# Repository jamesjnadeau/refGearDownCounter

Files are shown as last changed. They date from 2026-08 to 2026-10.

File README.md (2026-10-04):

# Ref Gear — Down Counter

Football down counters — the wrist-worn devices a referee uses to track which
down it is. This repository covers the **mechanical** ones. Both models are
here as OpenSCAD source, each with a test suite, and can be built from this
repository alone:

- [down-indicator-selector/](down-indicator-selector/) — the slider down
  counter, three printed parts.
- [down-indicator-string/](down-indicator-string/) — the finger-loop down
  indicator, one printed part.

The slider began in Onshape and was converted on 2026-08-25. The Onshape
documents are still recorded below, because the band lugs exist only there
and are not yet in the OpenSCAD model.

## These are not the Watchy ref counter

The **electronic** ref counter — an ESP32-C6 board running countdown timers on
a Watchy e-paper panel — is a separate project in its own repository,
[watchy-ref-counter](https://github.com/jamesjnadeau/watchy-ref-counter). That
is a different product with different hardware and different geometry.

The two are related only in purpose — both are officiating aids for football.
**Do not carry dimensions between them.** An earlier revision of the lugs spec
did exactly that, projecting a ~43 x 53mm case from the Watchy waterproof case
spec onto a part that actually measures 34 x 79mm, and every figure derived
from it was wrong. This repository was split out of that one on 2026-08-23 so
the two cannot be confused again.

## What you need to build

Both models build with the same tools. Nothing else is needed, and no file in
the repository has to be changed first.

| Tool | Version | Needed for |
| --- | --- | --- |
| [OpenSCAD](https://openscad.org/) | 2021.01 | `make stl` and `make test`. The tests' exact-volume figures were verified against this release; another release may shift them. |
| GNU Make | 4.4.1 used; any recent release should do | `make stl` and `make test` |
| Python | **3.12 or newer**, with the `venv` module | `make test` only. The pinned `numpy` and `scipy` do not install on anything older. |
| DejaVu Sans (font) | any | The slider's numerals. It is not vendored. See the warning below. |

The finger-loop model's fonts (Archivo) are vendored in
`down-indicator-string/fonts/` and need no installation.

`make test` creates a `.venv` in the model's directory and installs the pinned
packages from `requirements.txt` (`trimesh`, `numpy`, `scipy`, `rtree`,
`pytest`), so the first run needs network access to PyPI. `make stl` needs
neither Python nor the network.

On Debian 13 this is everything:

    apt-get install openscad make python3 python3-venv fonts-dejavu-core

Then, in either model's directory:

    make stl      # the printable STL files, in build/
    make test     # render the model and check it against the tests

**If DejaVu Sans is missing, `make stl` does not fail and prints no warning.**
OpenSCAD 2021.01 substitutes another face without a word, and the slider's
numerals come out in the wrong shape. The tie bar that holds the middle of the
"4" in place is positioned for DejaVu Sans. So run `make test` once on a new
machine before printing the top shell. Tried on 2026-10-03 with DejaVu Sans
hidden and Archivo substituted: `make stl` exited normally, and `make test`
failed two of its 64 tests. A different substitute face has not been tried and
may not be caught.

Checked on 2026-10-03 on Debian 13 with the versions above and Python 3.13.5.
Other operating systems have not been tried.

## Contents

| File | What it is |
| --- | --- |
| [2026-08-22-band-lugs-design.md](2026-08-22-band-lugs-design.md) | Design and as-built record for the spring-bar band lugs, the squared end corners, and the removal of the unprintable "4" counter. Built 2026-08-22, not yet printed. |
| [2026-08-24-finger-loop-indicator-design.md](2026-08-24-finger-loop-indicator-design.md) | Design for the finger-loop down indicator: a wrist body anchoring a bungee cord that loops over a finger. Modelled in OpenSCAD under `down-indicator-string/`, not in Onshape. |
| [down-indicator-string/](down-indicator-string/) | The OpenSCAD model for the above, with a `pytest` suite that renders it and asserts against the mesh. |
| [down-indicator-selector/](down-indicator-selector/) | All three parts of the slider down counter, converted out of Onshape into OpenSCAD on 2026-08-25, with the same kind of test suite and Onshape's own exports kept alongside as reference meshes. |
| Parts lists | Draft, with unknowns marked. [Slider](down-indicator-selector/PARTS.md), [finger loop](down-indicator-string/PARTS.md). |
| Assembly steps | Draft, with unknowns marked. [Slider](down-indicator-selector/ASSEMBLY.md), [finger loop](down-indicator-string/ASSEMBLY.md). |
| [AGENTS.md](AGENTS.md) | Working notes for agents. Chiefly: if you cannot delete something you created in Onshape, hand back an explicit cleanup list rather than leaving orphans unmentioned. |
| [LICENSE](LICENSE) | Open Community License v1.1, verbatim. See [Licence](#licence). |

## The mechanical slider down counter

A three-part printed slider. A knob rides in a slot in the top plate and
indexes between four stations; the numbers 1–4 engraved alongside the slot
read off the current down.

### The move to OpenSCAD

All three parts have been converted to OpenSCAD and live in
[down-indicator-selector/](down-indicator-selector/), so the counter can be
built without opening Onshape. They are conversions of the **original**, so
they carry no lugs. That README records what the conversion does and does not
carry over — chiefly the typeface, the two non-tangent corner arcs, and the
floating counter of the 4, which is the one thing deliberately fixed rather
than reproduced.

Two things it turned up that were not recorded anywhere before:

- **How the three parts stack.** The assembly in Onshape is empty, so this was
  read off the geometry: the bottom shell seats against the cavity ceiling and
  stands 1.1mm proud of the skirt, the button's flange lifts 0.4mm in its
  pocket, and its boss stands 1.9mm clear of the top face. Case thickness
  8.2mm.
- **The bottom shell does not fit the cavity.** The cavity's 3° draft makes it
  widest at the ceiling and narrowest at the mouth the bottom shell enters
  through, leaving about 0.18mm of interference per side. The owner confirmed
  on 2026-10-03 that the two shells are meant to press together.

### Onshape models

| | |
| --- | --- |
| Original (do not modify) | `3db840dfeff4095d8508aa97`, workspace `468073bad9de0e9ca2287d8a` |
| Working copy (edit this) | `00b1e7c9d07aec2789568fab`, workspace `f48449999f7a6cf5db9ca973` |

Both documents are the work of James Nadeau, who authored the original model
and holds the rights licensed under [OCL v1.1](#licence). Nothing here is
derived from a third party's design.

The copy was made by hand — the API cannot clone a document. Working in the
copy keeps the original intact and preserves the parametric feature tree.

Elements in the working copy:

| Element | ID |
| --- | --- |
| `top` | `c8988bf041b2bcfcdef1a5a4` |
| `Bottom` | `683c1e415929ccc1972183f3` |
| `button` | `549b45f983101a2bbf977db6` |
| `Assembly 1` | `1e37806a3e2b45bacbff18d4` — **empty**, no instances or mates |
| `BOM : Assembly 1` | `e0e801cd186e08b5a415de05` |

Because the assembly carries nothing, there is no mate data describing how the
parts stack. The two shells are nonetheless modelled in a shared coordinate
space: the top's inner end face and the bottom's outer end face both sit at
y = −15, so the shells nest directly.

### Parts, as measured 2026-08-22

| Part | Size | Notes |
| --- | --- | --- |
| `top` | 79.00 x 34.00 x 7.10mm | Solid plate z = 0 to +3.10; 2.0mm skirt wall z = −4.00 to 0 around the cavity the bottom nests in. Carries the slot, the numbers, and now the lugs. |
| `Bottom` | 75.00 x 30.00 x 5.10mm | Four index holes, radius 3.02mm, at x = 0 and y = 0, 15, 30, 45. |
| `button` | 12 x 12 x 5mm | Flanged top-hat with a hollow bore: a 12mm flange, ~1mm thick, under a raised boss. |

With the lugs fitted the top plate now measures **92.00mm** end to end; the
79.00mm figure is the case body alone.

### How it works

The slot in the top plate is a racetrack running y = 0 to 45, stepped: a
13mm-diameter internal pocket, narrowing to an 8.4mm opening at the top face.
The button's 12mm flange sits captive in the pocket and cannot pass back out
through the 8.4mm opening, while its boss protrudes for a thumb. Sliding it
along the slot moves it between the four stations set by the holes in the
bottom plate, at 15mm spacing.

The detent is a **magnetic pin**, as the owner confirmed on 2026-10-03. The
holes are its stations: the pin slides between the indicator positions and is
held locked at each one until the referee moves it. The magnets are common
6mm x 2mm ones, as the owner said on 2026-10-03. The pin and the magnets are
not modelled — the assembly is empty and no fastener is drawn — so the pin's
size, how many magnets there are, and where they sit are not recorded here.

### Field use

The owner has used this counter in games, as reported on 2026-10-04. It is a
pocket counter: it is carried in a pocket like the
[Football Umpire Counter](down-counter-umpire/), without that counter's track
for the ball's position on the field. It has no strap and needs none.

The counter the owner wears on the wrist is a different one, the 2 by 2 wrist
counter in [down-indicator-watch/](down-indicator-watch/).

### Current state

Built into the working copy on 2026-08-22, as two FeatureScript features
appended to `top`:

- `Watch lugs` (`F11dhRn0iQOtIjw_2`) — 20mm spring-bar lugs, horns flush with
  the side walls, squared end corners, teardrop spring-bar bores, and deletion
  of the floating "4" counter. Parametric: `bandWidth`, `barStandoff`,
  `tipMargin`, `barHoleDia`, `teardropDown`.
- `Lug edge chamfers` (`Fg13g2ZpNtzIeQs_3`) — 0.5mm chamfer on the horn tips,
  last in the tree so it reaches geometry the original chamfer features cannot.

The original feature tree is untouched ahead of these two; rolling back past
both restores the previous case exactly. Full dimensions and reasoning are in
the [lugs spec](2026-08-22-band-lugs-design.md).

**Two Feature Studio elements are load-bearing and must not be deleted**, as
each carries the source for one of the features above:

| Feature Studio | ID — check this, not the name | Carries |
| --- | --- | --- |
| `ClaudeFS_watchLugs2` | `058db78c7f1aef7b10e6357e` | `Watch lugs` |
| `ClaudeFS_lugChamfers2` | `a9c3a085e56c94f216aaf9f3` | `Lug edge chamfers` |

**Identify these by ID, not by name.** Reissuing a feature under an existing
`fsElementName` does *not* reuse that element — it creates a new one with the
same name — so superseded Feature Studios can share a name character for
character with the live one. Open the tab in Onshape and read the `/e/<id>`
segment of the URL to tell them apart.

Also do not confuse `Draft 1` in the feature tree with a leftover draft: it is
an original taper feature on the case walls, and deleting it changes the
geometry.

**Not yet printed.** A single-end test piece with a real spring bar and strap
should come before a full case print, and the wear orientation still needs
confirming — see the spec.

## The finger-loop down indicator

A third device, and the first one whose model was version-controlled here
rather than living in Onshape. A 40 x 30 x 6.7mm body on a 20mm watch strap,
with two 7mm through-holes. Each hole has a 7mm channel on the watch face
running out to one side edge and a matching channel on the wrist side running
out to the other, so a threaded cord makes two right-angle bends inside the
body and is held by its own path rather than by a knot. The cord runs over the
back of the hand and loops over a finger; the finger is the down selector.

It reuses the down counter's spring-bar lug geometry — 20mm band, 20.2mm gap,
teardrop bores — and nothing else. Its footprint is its own.

The cord is 1/8" bungee cord. The owner's strap is a 24mm-wide Velcro strap,
though any suitable strap that fits would do; the lugs as modelled take a 20mm
band, and that difference is not yet reconciled.

See [the design](2026-08-24-finger-loop-indicator-design.md) and
[down-indicator-string/README.md](down-indicator-string/README.md).

## Related Onshape documents

| Document | ID | Status |
| --- | --- | --- |
| Football Umpire counter | `e2228a8db539c63d2157e3cf`, workspace `2b4b489ae8b749f04039d1b5` | **Not inspected.** Same element structure as the down counter — three Part Studios, an assembly and a BOM — but nothing here has been verified against it. |

## Working on these models

Two environment constraints, both hit during the 2026-08-22 session and both
recorded in full in the spec's session notes:

- **`create_extrude` and `create_offset_plane` return HTTP 400** on the working
  copy for every argument combination, while `create_sketch` succeeds on the
  same element. Build with `write_featurescript_feature` instead; it works.
- **The Onshape account is at the free-tier 10-document cap**, so
  `create_document` returns 409 and throwaway scratch documents are not
  available for diagnosis.

## Licence

**OCL v1.1** — the [Open Community
License](https://github.com/OpenCommunityLicence/OpenCommunityLicence)
published by Prusa Research. No add-on conditions apply. The full text is in
[LICENSE](LICENSE).

In short: as a non-commercial end user you may use, copy, modify and hack this
work freely, and if you distribute derivatives you must do so under OCL as
well. A business may use and modify it internally, including for internal
production and repair, but may not replicate it commercially without a
separate licence. The work must not be subjected to automated text or data
mining without explicit permission.

The licence covers the design work recorded here: the OpenSCAD models, the
documentation, and the corresponding Onshape geometry. The OpenSCAD models in
this repository are enough to build the printed parts. The band lugs for the
slider are the exception: they exist only in the Onshape working copy.

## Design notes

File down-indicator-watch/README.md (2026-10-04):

# Wrist down counter, 2 by 2

A down counter worn on the wrist. One button moves between four positions set
in a 2 by 2 square, 14mm apart. There are two tops to choose from: one for a
watch strap on spring bars, one for a strap threaded through it.

Source document these were exported from:
https://cad.onshape.com/documents/00b1e7c9d07aec2789568fab/w/f48449999f7a6cf5db9ca973/e/4cc8a07cd495c58cc3707666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

The STEP files here are the design. They are the owner's exports and are not
to be redrawn or changed.

> **State of this page.** Every size below was measured from the STEP files on
> 2026-10-04 with OpenCascade 8.0. Nothing was printed or assembled. Anything
> marked *inferred* was read off the geometry and is not the owner's word.

## The files

| File | Part | Print | Size | Solid volume |
| --- | --- | --- | --- | --- |
| `top.step` | top shell for a spring-bar strap | 1 of the two tops | 34 × 50 × 7.1mm | 4 139mm³ |
| `top-elastic-strap.step` | top shell for a threaded strap | 1 of the two tops | 34 × 50 × 7.1mm | 4 229mm³ |
| `Bottom.step` | bottom shell | 1 | 30 × 30 × 5.1mm | 4 019mm³ |
| *not in this folder* | button | 1 | see below | |

Each file holds one closed, valid solid. Meshed at 0.01mm, each comes out as
one watertight body. Slicers that read STEP (PrusaSlicer, OrcaSlicer, Bambu
Studio) open them directly; there are no STL files here.

**There is no button file in this folder.** The button from
[`down-counter-umpire/button.step`](../down-counter-umpire/) is the one to
print. The owner said on 2026-10-04 that this counter, the slider and the
Umpire Counter "all use the same button/pin and magnets". The files agree: that
button fits both tops and the bottom shell with no overlap at all four
positions, and the openings, pockets and holes are the same sizes as that
counter's.

**Both tops** share the same middle: a 3.1mm plate with a 4.0mm skirt around a
30mm square cavity. The opening is a rounded square 22.4mm across, with a 27mm
pocket 1.4mm high underneath that keeps the button's flange captive. The
button is free to move anywhere in the square; there are no tracks between the
positions. **Neither top carries numerals or any other marking.**

**`top.step`, for a spring-bar strap.** Four horns, two at each end, each 6mm
wide and 8mm long. The gap between a pair is **22.0mm**. Each horn has a 1.1mm
cross hole right through it, drawn as a teardrop so it prints without support,
4mm out from the body. *Inferred:* the holes take the tips of a watch spring
bar, so this top takes a **22mm** watch strap and two 22mm spring bars. Note
that the other counters in this repository are drawn for 20mm straps. The
holes at one end sit 0.45mm lower than at the other; recorded, not changed.

**`top-elastic-strap.step`, for a threaded strap.** No horns and no cross
holes. Each end has an opening **24.0mm** wide and 5mm long, closed at the tip
by a low rounded bar of 3mm radius. *Inferred:* the strap passes over the bar
and down through the opening at each end, so this top takes a strap up to
**24mm** wide, with no room to spare at 24mm, and needs no spring bars. The
owner's own strap is a 24mm Velcro strap; see [Field use](#field-use).

**Bottom shell.** Four round holes, 6.03mm across and 3.1mm deep, over a 2.0mm
floor, on a 14mm square.

## Parts list

| Item | Qty | What is known |
| --- | --- | --- |
| Top shell, printed | 1 | `top.step` or `top-elastic-strap.step` |
| Bottom shell, printed | 1 | `Bottom.step` |
| Button, printed | 1 | No file here. `../down-counter-umpire/button.step`, 12 × 12 × 5mm (owner, 2026-10-04) |
| Magnets | **not recorded** | 6mm × 2mm discs, the same as the slider and the Umpire Counter (owner, 2026-10-04); the holes are the same 6.03mm. The bottom shell has 4 holes that take one each, with 1.1mm to spare in depth. How many magnets, and where they sit, is not recorded. |
| Pin | **not recorded** | The same pin as the slider and the Umpire Counter (owner, 2026-10-04). It is not drawn or sized anywhere. *Inferred:* one, 6mm across. |
| Strap | 1 | With `top.step`: a 22mm watch strap. With `top-elastic-strap.step`: a strap up to 24mm wide. Type and length not recorded. |
| Spring bars | 2 with `top.step`, 0 with the other | For a 22mm strap, with tips that fit a 1.1mm hole. Length and supplier not recorded. |
| Fasteners, glue | 0 | None in the files. The shells press together. |

## How it goes together

As far as the files show. *All of this is inferred from the geometry;* the
Onshape assembly was not exported.

1. Fit the magnets and pin. Where they go is not recorded.
2. Lay the top shell face down. Drop the button into the opening, sleeve
   first, so its flange rests in the pocket.
3. Press the bottom shell into the skirt, holes towards the button. The button
   must go in first: once the shells are together its flange cannot pass the
   opening.
4. Fit the strap: on two spring bars between the horns, or threaded over the
   bar at each end.

The bottom shell seats against the underside of the plate and stands 1.1mm
proud of the skirt. The finished counter is 34 × 50mm and 8.2mm thick, 10.1mm
over the button, which stands 1.9mm above the face.

## Fit, checked on the solids

- **The shells are a press fit.** The cavity is 30.0mm square at the plate and
  tapers to about 0.18mm per side narrower than the bottom shell at its mouth,
  with a small lead-in at the very edge. This is the slider's fit, which the
  owner confirmed is intended. The bottom shell is square, so it goes in any
  of four ways round.
- **The Umpire Counter's button clears both shells** at all four positions,
  with either top.
- **A 6mm × 2mm magnet fits the holes and the button's bore** on paper, with
  0.015mm a side. *Inferred:* printed holes usually come out a little small,
  so expect a push fit.

## Field use

The owner has worn this counter in at least 10 games in the 2026 season, as
reported on 2026-10-03 and confirmed as this model on 2026-10-04: "the one
with 4 slots in a 2 by 2 configuration". It is worn on a 24mm Velcro strap,
and the owner reports that the strap slots as sized keep it from sliding.
*Inferred:* a 24mm strap through slots is `top-elastic-strap.step`; it is too
wide for the 22mm gap between the horns of `top.step`.

## Not known

- How many magnets, where they sit, and which way their poles face. What the
  pin is.
- Which position stands for which down. Nothing on the part says.
- The strap for each top: its type and length. Either top may be used; the
  builder picks one.
- Print material, layer height, and which face goes on the bed.

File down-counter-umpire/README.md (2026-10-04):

# Football Umpire Counter

A flat pocket counter with two tracks. One button slides over four positions
marked 1 to 4, for the down. A second button slides over seven positions, for
where on the field the ball was last spotted. It is carried in a pocket, not
worn, and set by feel: one corner is cut off so the hand can tell which way it
sits. The owner has used one for years.

Source document these were exported from:
https://cad.onshape.com/documents/e2228a8db539c63d2157e3cf/w/2b4b489ae8b749f04039d1b5/e/6bc132c3cf1c9548ce42d1b0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

The STEP files here are the design. They are the owner's exports and are not
to be redrawn or changed.

> **State of this page.** Every size below was measured from the STEP files on
> 2026-10-04 with OpenCascade 8.0. Nothing was printed or assembled. Anything
> marked *inferred* was read off the geometry and is not the owner's word.

## The files

| File | Part | Print | Size | Solid volume |
| --- | --- | --- | --- | --- |
| `top.step` | top shell | 1 | 64.07 × 79.14 × 7.1mm | 13 411mm³ |
| `Bottom.step` | bottom shell | 1 | 60 × 75 × 5.1mm | 21 652mm³ |
| `button.step` | button | **2**, one per slot | 12 × 12 × 5mm | 169mm³ each |

Each file holds one closed, valid solid. Meshed at 0.01mm, each comes out as
one watertight body. Slicers that read STEP (PrusaSlicer, OrcaSlicer, Bambu
Studio) open them directly; there are no STL files here.

**Top shell.** A 3.1mm plate with a 4.0mm skirt, walls 2mm. Two stepped slots:
8.4mm wide where the button shows through, with a 13mm wide, 1.4mm high pocket
underneath that keeps the button's flange captive. The four-position slot
travels 45mm. The seven-position slot travels 55mm and sits 30mm to the side.
The numerals 1 to 4 are cut through the plate between the slots. A V-shaped
mark is cut through beside the fourth, middle, position of the seven. The cut
corner is at the "1" end, on the four-position side, 7mm along each edge.

**Bottom shell.** Eleven round holes, 6.03mm across and 3.1mm deep, over a
2.0mm floor: four on a 15mm pitch and seven on a 9.2mm pitch. Its matching
corner is cut 5mm along each edge.

**Button.** A ring, not a cap: an 8.0mm sleeve on a 12mm flange 1.0mm thick,
with a 6.03mm bore straight through. It is the same part as the slider's
button in [`down-indicator-selector/`](../down-indicator-selector/); the two
measure the same.

## Parts list

| Item | Qty | What is known |
| --- | --- | --- |
| Top shell, printed | 1 | `top.step` |
| Bottom shell, printed | 1 | `Bottom.step` |
| Button, printed | 2 | `button.step`, printed twice |
| Magnets | **not recorded** | 6mm × 2mm discs, the same as the slider (owner, 2026-10-03). The bottom shell has 11 holes that take one each, with 1.1mm to spare in depth. Each button's bore is 5mm long. How many magnets, and where they sit, is not recorded. |
| Pin | **not recorded** | "The same magnets and pin" as the slider (owner, 2026-10-03). It is not drawn or sized anywhere. *Inferred:* one per button, 6mm across, since the bore and the holes are both 6.03mm. |
| Strap | 0 | None. It has no strap fitting. |
| Fasteners, glue | 0 | None in the files. The shells press together. |

## How it goes together

As far as the files show. *All of this is inferred from the geometry;* the
Onshape assembly was not exported.

1. Fit the magnets and pins. Where they go is not recorded.
2. Lay the top shell face down. Drop a button into each slot, sleeve first, so
   its flange rests in the pocket.
3. Press the bottom shell into the skirt, holes towards the buttons, cut corner
   to cut corner. The buttons must go in first: once the shells are together
   the flanges cannot pass the slots.

The bottom shell seats against the underside of the plate and stands 1.1mm
proud of the skirt. The finished counter is 64.07 × 79.14mm and 8.2mm thick,
10.1mm over the buttons, which stand 1.9mm above the face.

## Fit, checked on the solids

- **The shells are a press fit.** The cavity is 60.0 × 75.0mm at the plate and
  tapers to about 0.18mm per side narrower than the bottom shell at its mouth,
  with a small lead-in at the very edge. This is the slider's fit, which the
  owner confirmed is intended.
- **The buttons clear both shells** at all eleven positions: no overlap with
  the top or the bottom shell. The sleeve has 0.2mm a side in the slot, the
  flange 0.5mm a side and 0.4mm of lift in its pocket.
- **The seventh position has no spare travel.** The seven holes run from
  y = −5.0 to y = 50.2, and the slot above them from −5.0 to 50.0. At the last
  hole the button's sleeve is touching the end of the slot. It still lines up,
  with nothing left over. Recorded, not changed.
- **A 6mm × 2mm magnet fits the holes and the bore** on paper, with 0.015mm a
  side. *Inferred:* printed holes usually come out a little small, so expect a
  push fit.

## Not known

- How many magnets, where they sit, and which way their poles face.
- What the pin is: its length, its material, and whether it is a magnet stack.
- Print material, layer height, and which face goes on the bed.
- What each of the seven positions stands for. The V marks the middle one.
- Whether the numerals and the V need supports or bridging settings; they are
  cut through the full 3.1mm plate.

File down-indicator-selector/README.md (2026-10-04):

# Down indicator selector

The mechanical slider down counter, converted out of Onshape so the whole
thing can be worked on with nothing but OpenSCAD.

Three printed parts. The **top shell** is the plate a referee reads: 34 × 79 ×
7.1mm, with a stepped slot running its length and the numerals 1–4 cut through
beside it. The **bottom shell** nests into the cavity underneath it and sets
four stations 15mm apart. The **button** rides captive in the slot between
them, and which station it is on is the down.

| | | |
| --- | --- | --- |
| `down_indicator_selector.scad` | top shell | 34 × 79 × 7.1mm |
| `down_indicator_selector_bottom.scad` | bottom shell | 30 × 75 × 5.1mm |
| `down_indicator_selector_button.scad` | button | 12 × 12 × 5mm |

```bash
make stl
```

```bash
make test
```

Tools: OpenSCAD 2021.01, GNU Make, the DejaVu Sans font, and for `make test`
Python 3.12 or newer with `venv`. The font is **not** vendored, and
`make stl` does not fail without it. The full list is in
[the repository README](../README.md#what-you-need-to-build).

## Where it came from

Onshape document `3db840dfeff4095d8508aa97`, workspace
`468073bad9de0e9ca2287d8a` — the original, do-not-modify copy. Read on
2026-08-25, at source microversion `49bf20ec9ce4d74dcad3203d`.

| Part Studio | Element |
| --- | --- |
| `top` | `8198d257a0b49b205e551477` |
| `Bottom` | `4770465acc52710e74b35fe2` |
| `button` | `82000ae215407b6dae7e9365` |

The conversion was made from the feature trees, not by tracing meshes. Every
dimension here is one of the originals' own: their variables (`holeSpaceing`
15, `holeDiameter` 8.4 on the top and 6.03 on the bottom, `cornerRadius` 6,
`buttonDiameter` 13, `shellWidth` 2, `textHeight` 7), their sketch
coordinates, and the depths, angles and radii on the extrudes, draft,
chamfers and fillets.

`reference/` holds Onshape's own exports of all three Part Studios, rescaled
from metres to millimetres and otherwise untouched. `make test` holds each
OpenSCAD model against its own reference, wall by wall.

### Coordinates are Onshape's, kept verbatim

None of the three parts is centred on the origin, and deliberately so: they
share a frame in plan. The slot runs from y = 0 to y = 45 on x = 0, and those
four stations are exactly where the bottom shell's holes sit.

In z they do not share a frame — each is drawn about its own z = 0, as it is
in Onshape. The top shell's z = 0 is the underside of its plate; the bottom
shell's is the floor of its four holes; the button's is the top of its flange.
See [How the three fit](#how-the-three-fit) for the arithmetic.

## How faithful it is

| Part | This model | Onshape | |
| --- | --- | --- | --- |
| top shell | 7819.4mm³ | 7832.5mm³ | 0.17% |
| bottom shell | 10829.4mm³ | 10828.5mm³ | 0.01% |
| button | 168.5mm³ | 168.6mm³ | 0.09% |

Every flat wall, the cavity, its draft, the slot, the pocket, the ledge, the
stations and the button's bore agree to within 0.02mm, which is the resolution
the tests measure at. On the top shell, take the numerals off both sides and
the two solids agree to about two parts in ten thousand — the numerals are the
difference, and the reason is the typeface.

Four things are worth knowing before trusting a dimension.

### The typeface

The original is set in **Open Sans**, which OpenSCAD cannot count on finding
installed. The default here is DejaVu Sans, which is a heavier face: the same
numerals cut about 20% more plate away. If Open Sans is installed, setting
`textFont = "Open Sans"` gets closer to the original.

The four numerals are *not* on the 15mm station pitch. They were placed by
hand in the original and drift about 3mm over the run. `textCentres` holds the
measured ink centre of each one rather than a regenerated layout, so a
substituted font lands each numeral where Onshape's is rather than walking it
along the plate. Putting them on the pitch is a one-line change and probably
an improvement, but it is a design change, not a conversion.

### The swung corners

Two of the three rounded corners of the footprint are not tangent fillets. The
−X/−Y corner is an ordinary 8mm fillet, but the two +X corners were struck on
arcs of 5·√2 ≈ 7.071mm through the tangent points an 8mm fillet would have
given. Such an arc is tangent to neither wall: it bulges 0.0711mm past both
and meets them at a slight kink, which is why the part measures 34.07 × 79.14
rather than 34 × 79.

This is almost certainly a slip in the original sketch, and it is tempting to
read it as a 0.07mm rounding error and square it off. It is not: at the corner
diagonal, where the difference is widest, the swung arc comes **0.48mm**
closer to the corner than a fillet would. So the default reproduces it.
`cornerSwing = cornerRadius + shellWidth` gives the fillets that were probably
intended.

Reproducing it costs one thing. A footprint with those arcs in it is slightly
concave, and the shell is built as a stack of bands whose walls are convex
hulls, so along the walls between those two corners the top chamfer and the
bottom fillet come out up to 0.0711mm narrow. The walls and corners themselves
are clipped back and are exact. See the notes in `lib/shell.scad`.

### The floating counter of the 4, which is fixed here

The numerals are cut clean through the plate, which leaves the triangle inside
the 4 attached to nothing. In the original it drops out of the print: Onshape
reports two solid bodies for `top` for exactly that reason, and the working
copy's `Watch lugs` feature ends by deleting the stray one.

**This is the one place the model deliberately departs from the original.** It
does what stencil faces do: leaves a 0.7mm bar of plate uncut across the
diagonal stroke, tying the loose piece back to the rest. The numeral still
reads as a 4. `make stl` gives a single closed solid.

The bar is a rectangle in glyph coordinates, so it depends on the face in use
— changing `textFont` or `textSize` means checking it still lands, and the
test that the part renders as one closed solid is what catches a tie that has
missed. `tiedNumeral = 0` cuts the numerals exactly as the original does,
floating counter and all.

### The bottom shell does not fit the cavity

Not a conversion artefact — it is what the originals measure, and the reason
it is under Fidelity rather than under a heading of its own is that the model
reproduces it rather than quietly correcting it.

The top shell's cavity is drafted 3° and is **widest at its ceiling**, so it
narrows toward the opening the bottom shell has to come in through: 30.000 ×
75.000 at the ceiling, 29.633 × 74.633 at its tightest section. The bottom
shell is 30.000 × 75.000. That is **0.18mm of interference per side**, and the
bottom shell's only chamfer is on the face that goes in last, so nothing leads
it in.

It is a press fit on purpose: the owner confirmed on 2026-10-03 that the two
shells are meant to press together. `draftAngle` is the parameter that sets
it, and `tests/test_fit.py` pins the number so any change has to be
deliberate.

## How the three fit

The Onshape assembly is empty — no instances, no mates — so nothing on either
side records how the counter stacks up. This is read off the geometry, and
`tests/test_fit.py` checks every line of it.

In the top shell's frame:

| | z | |
| --- | --- | --- |
| bottom shell | −5.10 … 0.00 | top face against the cavity ceiling, 1.10 proud of the skirt |
| top shell | −4.00 … 3.10 | |
| button flange | 0.00 … 1.00 | 1.0mm flange in a 1.4mm pocket, so 0.40 of lift |
| button boss | 1.00 … 5.00 | stands 1.90 clear of the top face |
| bottom's stations | −3.10 … 0.00 | the button's bore runs 0.00 … 5.00, straight over them |

Case thickness 8.20mm; 10.10mm over the boss. In plan the button has 0.50mm
of clearance in the pocket and 0.40mm in the opening, and its 12mm flange
cannot pass back out through the 8.4mm opening.

The detent itself is **not modelled, here or in Onshape**. The button's bore
and the bottom shell's holes are both 6.03mm, and what runs through the one
into the other is a **magnetic pin**, as the owner confirmed on 2026-10-03.
It slides between the indicator positions and is held locked at each station
until the referee moves it. The magnets are common 6mm x 2mm ones, as the
owner said on 2026-10-03. No fastener is drawn anywhere, so the pin's size,
how many magnets there are, and where they sit are not recorded here.

## Field use

The owner has used this counter in games, as reported on 2026-10-04. It is a
pocket counter: it is carried in a pocket like the
[Football Umpire Counter](../down-counter-umpire/), without that counter's
track for the ball's position on the field. It has no strap and needs none. The
model here has no strap slots or lugs, which agrees with that.

The counter the owner wears on the wrist is a different one, the 2 by 2 wrist
counter in [`down-indicator-watch/`](../down-indicator-watch/).

## Layout

| | |
| --- | --- |
| `down_indicator_selector.scad` | the top shell: every parameter, the assertions, and the four-way difference that makes the part |
| `down_indicator_selector_bottom.scad` | the bottom shell |
| `down_indicator_selector_button.scad` | the button, as a solid of revolution |
| `lib/profile.scad` | the plan outlines, and the arc maths behind the swung corners |
| `lib/shell.scad` | banded solids: fillets, chamfers, the drafted cavity, and the plain plate |
| `lib/slot.scad` | the stepped slot and its pocket |
| `lib/numbers.scad` | the numerals, and the tie across the 4 |
| `reference/` | Onshape's exports of all three originals, in millimetres |
| `tests/` | pytest, rendering the models and asserting against the meshes |

## Still in Onshape

Nothing of this counter — all three parts are here. The lugs are a different
matter: they are a feature of the *working* copy, not of this original, and
they are still unbuilt. See
[../2026-08-22-band-lugs-design.md](../2026-08-22-band-lugs-design.md).

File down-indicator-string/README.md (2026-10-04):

# Finger-Loop Down Indicator — OpenSCAD model

A wrist-worn body that anchors a bungee cord looping over the back of the hand
and around a finger. Which finger the loop sits on is the down.

Design and reasoning: [../2026-08-24-finger-loop-indicator-design.md](../2026-08-24-finger-loop-indicator-design.md).

## Build

    make stl      # -> build/down_indicator_string.stl
    make test     # render the model and assert against the mesh
    make clean

`make` creates `.venv` on first use and installs the pinned dependencies from
`requirements.txt`.

Tools: OpenSCAD 2021.01, GNU Make, and for `make test` Python 3.12 or newer
with `venv`. The fonts are vendored. The full list is in
[the repository README](../README.md#what-you-need-to-build).

## Parameters

Every parameter is declared at the top of `down_indicator_string.scad` and can be
overridden without editing the file:

    openscad -o build/wide.stl -D bandWidth=18 down_indicator_string.scad

| Parameter | Default | Notes |
| --- | --- | --- |
| `bodyLen` | 40.0 | Along the forearm |
| `bodyWid` | 30.0 | Across the wrist |
| `bodyT` | 6.7 | Sets the trough floor: `bodyT - (troughDia/2 + troughOffset)`, 4.45mm at defaults, min 2.0mm |
| `edgeCham` | 1.0 | 45° bevel where each outer wall meets a face; 0 disables |
| `cordDia` | 7.0 | Through-hole diameter. The troughs are sized separately |
| `holeY` | 6.0 | Hole centres at `(0, +holeY)` and `(0, -holeY)` |
| `troughDia` | 2.5 | Surface trough diameter; independent of `cordDia` |
| `troughOffset` | 1 | Trough axis off its face: positive sinks it into the body for a groove deeper than a half-round, negative lifts it out for a shallower one, 0 puts the axis on the face |
| `bandWidth` | 20.0 | 18 if the 4.9mm horns prove marginal |
| `bandClear` | 0.2 | Added to `bandWidth` for the lug gap |
| `barStandoff` | 4.5 | |
| `tipMargin` | 2.0 | |
| `barHoleDia` | 1.1 | |
| `tipChamfer` | 0.5 | Must stay under half the horn thickness (2.45mm at defaults) |
| `teardropDown` | true | Apex toward the wrist side, for a face-down print |
| `logoEnable` | true | Cuts the RefGear wordmark into both faces |
| `logoWidth` | 26.0 | Along the forearm; the mark stands a shade over 5:1 |
| `logoDepth` | 0.5 | Recessed into each face |
| `logoX` | -8.75 | Centre across the wrist; must be negative (see below) |
| `logoY` | 0.0 | Centre along the forearm |

Eight combinations are rejected outright rather than silently producing an
unbuildable part: less than 2.0mm of floor under a cord trough, a trough
offset that stops the trough being an open groove, horns thinner than 4.0mm,
holes or troughs that break out of the end, less than 2.0mm of wall between
the two cord holes, an edge chamfer at or past half the body thickness, an
edge chamfer at or past half the horn thickness, and a tip chamfer at or past
half the horn thickness. Two of these would otherwise render without an
error: merged holes sever the slab into two pieces, and an oversized tip
chamfer self-intersects the horn polygon and deletes all four lugs.

Five more guard the logo: a mark on the wrong side of the centre line, one
that reaches the cord holes, one past the side chamfer, one that runs off the
body end, and a pair of recesses leaving under 2.0mm of web between them.

The mark reads along the forearm, so it runs *alongside* the cord holes rather
than past them and cannot be centred across the wrist. Which side is not a
free choice: the watch-face troughs run out to +X and the wrist-side ones to
-X, so the mark belongs on -X, and mirroring the wrist copy -- which it needs
anyway to read the right way round on that face -- lands it on +X, clear of
its own troughs. One offset serves both faces, and `logoX` is asserted
negative because the positive mirror image of that arrangement lays each mark
straight across its own trough run.

## Fonts

The wordmark is built from `text()` against the two static Archivo faces
vendored in `fonts/`, under the SIL Open Font License (`fonts/OFL.txt`).
Neither the checkout nor the build needs Archivo installed system-wide, but
`FONTCONFIG_FILE` must point at `fonts/fonts.conf` -- the Makefile and the
test suite both set it, so `make stl`, `make test` and a bare `pytest` all
work unassisted. Invoking `openscad` by hand needs it set:

    FONTCONFIG_FILE=fonts/fonts.conf openscad -o build/x.stl down_indicator_string.scad

Three things make that indirection load-bearing rather than tidy. OpenSCAD
resolves faces only through fontconfig and ignores its own library font
directory; a face it cannot resolve is quietly substituted rather than
refused, so a missing font is a silent visual defect and not an error; and its
SVG reader drops `<text>` elements outright, so `refgear-logo.svg` cannot be
imported and imports as the bare underline alone. A *variable* Archivo is no
help either -- OpenSCAD honours no weight axis, rendering Black and Regular
identically and flattening the 900/400 contrast the mark is built on. Hence
two static files.

The tests render with the `openscad` CLI and assert against the resulting
mesh. The exact-volume assertions were verified against **OpenSCAD 2021.01**;
a different release may triangulate curved surfaces differently and shift
those figures within their stated tolerances.

## Hardware

As the owner uses it, confirmed 2026-10-03:

| | |
| --- | --- |
| Cord | 1/8" (3.2mm) bungee cord |
| Strap | 24mm-wide Velcro strap, though any suitable strap that fits would do |

The lugs as modelled take a 20mm band (`bandWidth` 20.0, a 20.2mm gap), which
is narrower than that strap. The model has not been changed to match:
`bandWidth = 24` leaves 2.9mm horns on the 30mm body, and the 4.0mm horn guard
rejects it. How the 24mm strap is fitted is not recorded.

## Print

Face down — the `z = bodyT` face on the bed. That puts strap tension along the
layers and makes the teardrop bores self-supporting.

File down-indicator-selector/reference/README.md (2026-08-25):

# Reference meshes

Onshape's own STL exports of the three Part Studios of document
`3db840dfeff4095d8508aa97`, workspace `468073bad9de0e9ca2287d8a`, taken
2026-08-25 at source microversion `49bf20ec9ce4d74dcad3203d`.

| File | Part Studio | Element |
| --- | --- | --- |
| `onshape-top.stl` | `top` | `8198d257a0b49b205e551477` |
| `onshape-bottom.stl` | `Bottom` | `4770465acc52710e74b35fe2` |
| `onshape-button.stl` | `button` | `82000ae215407b6dae7e9365` |

Onshape exports in metres. These copies have been rescaled to millimetres, to
match every other STL in the repository, and are otherwise the bytes Onshape
produced.

They are **tessellations, not the solids**. Onshape's chord tolerance flattens
every curve, and the smaller and rounder the part the worse it reads:

| | tessellated | B-rep |
| --- | --- | --- |
| `top` | 7826.4mm³ | 7832.5mm³ |
| `Bottom` | 10827.1mm³ | 10828.5mm³ |
| `button` | 164.0mm³ | 168.6mm³ |

The top's bounding box also misses the 0.0711mm corner bulge its solid has.
`tests/test_against_onshape.py` is written around all of that: strict on flat
faces, where a tessellation is exact, and loose on curved ones — which is why
the button is compared against its B-rep volume and its walls, not against
the volume of the mesh here.

They are here so the conversion can still be checked once nobody is opening
Onshape any more. Do not regenerate them to make a test pass.

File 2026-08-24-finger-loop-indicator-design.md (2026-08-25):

# Finger-Loop Down Indicator — Design

Status: **specified** 2026-08-24, not yet built
Scope: a wrist-worn body, modelled in OpenSCAD, that anchors a bungee cord
looping over the back of the hand and around a finger. Which finger the loop
sits on is the down.

## What this is, and what it is not

This is a **third** device in the family, and it shares geometry with neither
of the others by default:

- The **mechanical slider down counter** — Onshape, three printed parts, a
  knob indexing between four stations. See [README.md](README.md).
- The **electronic Watchy ref counter** — a separate repository,
  [watchy-ref-counter](https://github.com/jamesjnadeau/watchy-ref-counter).

The one thing carried across deliberately is the **spring-bar lug geometry**
from [the lugs spec](2026-08-22-band-lugs-design.md), because it is proven and
because a common band across the two devices is worth having. Every figure
imported is named in [Lugs](#lugs) with its source. Nothing else crosses over
— in particular the down counter's 79 x 34mm footprint does **not** apply
here, and importing it would repeat the error that spec was written to correct.

## Prior art

The commercial equivalent is a referee's down-indicator wristband: an elastic
band with a loop the wearer moves between fingers. This design replaces the
band-and-loop with a rigid body on a watch strap and a bungee loop, so the
device can share a strap with the mechanical counter.

## Where the work happens

**In this repository**, unlike the down counter. The model is OpenSCAD source
under `down-indicator-string/`, version-controlled, with a `pytest` + `trimesh` suite
that renders the model and asserts against the resulting mesh. No Onshape
document is involved, and none of the Onshape constraints recorded in
[AGENTS.md](AGENTS.md) apply.

## Coordinates

| Axis | Direction | Extent |
| --- | --- | --- |
| +X | across the wrist | −15 to +15 |
| +Y | along the forearm, toward the hand | −20 to +20 (body), ±26.5 with lugs |
| +Z | out of the watch face | 0 (wrist side) to 6.7 (face) |

The wrist side is z = 0 throughout. "Underside" in the lugs spec's sense means
−Z here too, so `teardropDown` keeps its original meaning.

## Geometry

### Body

A plain rectangular slab. Square in plan, no corner radius.

| Dimension | Value |
| --- | --- |
| Length, along the forearm | 40.0mm |
| Width, across the wrist | 30.0mm |
| Thickness | 6.7mm |
| Volume, blank | 8040.0mm³ |

**Square corners, not rounded.** The lug horns run flush to the side walls at
x = ±15, exactly as the down counter's do. A corner radius at the ±Y ends
would root the horns into the radius rather than into solid end material —
the failure the lugs spec diagnosed and fixed by squaring the corners. The
`cornerR` question does not arise: there is no such parameter.

### Edge chamfers

Every outer wall that a wearer can touch is bevelled **1.0mm at 45°** where it
meets each face: both side walls, all four horn tip faces, and the two body
end faces at the base of the band gap. The part is 6.7mm of hard plastic
against a wrist, and the long side walls are the edges that press into it.

| Quantity | Value |
| --- | --- |
| Chamfer | 1.0mm at 45° |
| Walls chamfered | side walls, horn tips, band-gap base |
| Walls left square | horn interiors, holes, channels, bores |
| Volume removed | 147.69mm³ |
| Full-thickness wall remaining | 4.7mm |
| Band gap, every height | 20.2mm |

The chamfers are **exact half-spaces, not swept surfaces.** Every outer wall
here is straight and every outer solid is a straight extrusion from z = 0 to
z = 6.7, so the material to remove at a wall with outward normal n at distance
d is simply {p·n − z > d − cham}, mirrored about z = t/2 for the other face.
No stepped approximation is involved and nothing is rounded.

**The horns' inner faces are deliberately left square.** They are what the
strap bears against, and the gap is sized to the strap — 20.2mm for a 20mm
band. Bevelling them would open the gap to 22.2mm at each face while leaving
20.2mm in the middle, so the strap would sit loose top and bottom and rock in
its own slot. They keep their full 6.7mm height.

The body end faces *at the base* of the gap are chamfered, because nothing
bears on them; they only need to not be sharp. That half-space faces inward
and would run on through the horns, so it is the one cutter here that is
bounded — clipped to the gap width.

The cord holes, the cord channels and the spring-bar bores are **not**
chamfered either. They are functional surfaces, and the cord and the bar want
the full section.

`edgeCham = 0` removes the chamfers and returns the square-edged part.

### Cord holes

Two through-bores, on the Y centreline, symmetric about the origin.

| Quantity | Value |
| --- | --- |
| Diameter | 7.0mm |
| Centres | (0, +10) and (0, −10) |
| Wall, hole edge to body end | 6.5mm |
| Wall, between the two holes | 13.0mm |
| Volume removed | 515.32mm³ |

### Cord slots

From each hole, a trough of the **same 7.0mm diameter** runs out to a side
edge — but the two troughs of a hole run to **opposite** edges. The watch-face
trough (axis at z = 6.7) runs to +X; the wrist-side trough (axis at z = 0)
runs to −X. Both holes share the same handedness, so the two face channels are
parallel and the two wrist channels are parallel.

That opposition is the whole design. A strand entering the face channel drops
through the hole and turns into the wrist channel heading the other way, so it
makes **two right-angle bends inside the body**. The bends are the retention:
the cord is held by the shape of its own path, not by a knot and not by a
pinch fit.

| Quantity | Value |
| --- | --- |
| Trough width at its own face | 7.0mm |
| Trough depth | 3.5mm |
| Floor left under each trough | 3.2mm |
| Run, hole centre to side edge | 15.0mm |
| Volume removed, holes and troughs together | 1440.61mm³ |

**The cord is threaded, not pressed in.** Away from the hole the two channels
sit on opposite sides of the body and never meet, so there is no open slot
along either run — the only full-thickness opening is the hole itself. This is
the deliberate consequence of the opposed routing, and the test suite pins it
down directly rather than leaving it to be inferred.

**6.7mm is a free choice, not a derived one.** An earlier revision of this
spec ran both of a hole's troughs to the same end, which made them overlap at
mid-thickness into a pressed-in slot, and 6.7mm was the thickness that gave
that slot a ~2mm neck. With opposed routing there is no neck, and the binding
constraint is instead the **floor under each trough**: `bodyT − cordDia/2`,
which the model asserts stays at or above 2.0mm. At the defaults that floor is
3.2mm.

### Lugs

Carried over from [the lugs spec](2026-08-22-band-lugs-design.md) as built,
with two figures re-derived because the end is 30mm wide here rather than
34mm.

| Dimension | Value | Source |
| --- | --- | --- |
| Band width | 20mm | Lugs spec, as built |
| Lug gap, inner face to inner face | 20.2mm | Lugs spec, as built |
| Horn thickness, each | **4.9mm** | **Re-derived**: (30 − 20.2) / 2 |
| Horn protrusion | 6.5mm | Lugs spec: standoff 4.5 + tip margin 2.0 |
| Bar standoff | 4.5mm | Lugs spec, as built |
| Spring-bar bore | 1.1mm, through, teardrop | Lugs spec, as built |
| Teardrop apex | Toward −Z | Lugs spec, as built |
| Tip chamfer | 0.5mm | Lugs spec, as built |
| Horn height | **6.7mm** | **Re-derived**: full body thickness |
| Lug-to-lug | **53.0mm** | **Re-derived**: 40 + 2 × 6.5 |

**The horns are 4.9mm thick, against 6.9mm on the down counter.** A 30mm end
minus a 20.2mm gap leaves less material per horn than a 34mm end does. 4.9mm
is still more than twice the down counter's 2.0mm wall and the bore leaves
5.6mm of material across the horn's height, but it is the thinnest structure
in this part and the one the print test should load first. `bandWidth = 18`
restores 5.9mm horns if it proves marginal; the model asserts horn thickness
stays at or above 4.0mm, so `bandWidth = 24` is rejected outright.

**53.0mm lug-to-lug** sits inside the 48–56mm span of a large watch, which the
79mm down counter could never reach. Orientation is not in question here: the
40mm axis runs along the forearm and the lugs sit on the 30mm ends.

### Trough and lug interaction

The troughs run in X at y = ±10, spanning y ∈ [6.5, 13.5] and [−13.5, −6.5].
The horns begin at y = 19.5. The two never meet in Y, so the troughs exit the
side walls in clear material with 6mm to spare and touch neither the horns nor
the bores.

This is the payoff of routing to the sides rather than the ends: the cord
leaves the body well clear of the strap, so nothing is pinned under the spring
bar.

## Print

Printed flat, **face down** — the z = 6.7 face on the bed. This matches the
down counter's orientation, puts strap tension along the layers rather than
across them, and makes the teardrop bores self-supporting with their apex
toward −Z, i.e. upward on the bed.

One consequence is unavoidable and worth stating plainly: the part is
symmetric in Z, so of the two troughs, whichever faces the bed prints as an
unsupported 7mm arch and whichever faces up prints as a clean valley.
Flipping the part swaps which is which — there is no orientation that makes
both clean.

The arch here is milder than it looks. Because the channels are opposed, the
bed-side arch has 3.2mm of solid floor above it rather than an open slot, so
sag shows up as a rougher channel surface, not as a closed passage. The
failure mode is a cord that drags where it should slide. Check the bed-side
channel on the first print and hand-ream it if the surface is poor.

## Verification

The model is checked by rendering it to STL and asserting against the mesh:
watertight, a single body, exact bounding box, exact volume at each build
stage, and point-containment probes proving that each face carries its channel
on its own side and nothing on the other, that 3.2mm of floor survives beneath
each trough, that both troughs reach their side edge, that the cord path is
threaded rather than open, that the holes go through, that the band gap is
clear, that the bores run through all four horns with the teardrop apex on the
−Z side, and that every outer wall is bevelled at both faces while staying
full height at mid-thickness.

The suite is mutation-tested, not merely green: reversing a trough's
direction, lifting a trough off its face, stopping the troughs short of the
edge, dropping the sign that mirrors the teardrop apex, chamfering only one
side wall, chamfering only one face, cutting the bevel at 30° instead of 45°,
chamfering the band-gap base at one end only, or bevelling a horn interior —
even just one of the four — each fail it.

Software cannot confirm the 4.9mm horns survive a wrist, or that two
right-angle bends hold a real bungee under a finger's pull. Both need the
print test.

## Open questions

**Bend retention is untested against a real bungee.** Two right-angle bends
through 6.7mm of body should hold an elastic cord by friction alone, but that
is a claim about a real material, not about geometry. Print a coupon — one
hole with its two channels — and pull a bungee through it before committing to
a full body. If it slips, the cheapest fixes in order are a smaller `cordDia`
for a tighter path, then a thicker `bodyT` for longer bends.

**Threading may be fiddly.** The cord has to be fed through a 7mm hole and
turned into a channel on the far face. With a soft bungee end that may need a
threading tool or a taped tip. This is the price of the opposed routing, which
is what makes the part hold the cord without a knot.

**Whether 1mm of chamfer is enough.** The outer walls are bevelled, which
takes the bite off the edges, but the wrist side is still a flat plate. If it
still presses uncomfortably the next step is a larger `edgeCham` — the guards
allow up to 2.4mm — or a fillet rather than a chamfer, which would need a
different construction than the half-spaces used here.

**The chamfer thins the trough floor at the side walls.** Where a cord channel
exits at x = ±15 the bottom chamfer takes 1mm off the 3.2mm floor, leaving
2.2mm at the extreme edge and tapering back to full within 1mm. That is the
thinnest the floor gets anywhere and it sits right where the cord bears as it
leaves the body. Watch it on the print test.

## Licence

OCL v1.1, as with everything in this repository. See [LICENSE](LICENSE).

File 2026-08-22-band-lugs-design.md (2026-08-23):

# Watch Band Lugs for the Down Counter Case — Design

Status: **built** 2026-08-22, not yet printed
Scope: add spring-bar lugs to the two short ends of the top case, square off the
end corners, and drop the unprintable counter of the "4"

## Which case this is, and which it is not

This spec covers the **mechanical slider down counter** — a separate project
from the electronic Watchy-based ref counter, which lives in the
[watchy-ref-counter](https://github.com/jamesjnadeau/watchy-ref-counter)
repository. The two are related in purpose, both being football down counters.
They share no hardware and no geometry.

The first revision imported dimensions from `2026-08-18-waterproof-case-design.md`
in that other repository, which describes the Watchy case — a different
product. Every figure so borrowed (~43mm wide, ~53mm long, split shell, gasket
groove, sealing land) was wrong for this part. Those imports are removed.
Nothing in the waterproof case spec constrains this design.

## Where the work happens

The model lives in Onshape, not in this repository.

| | |
| --- | --- |
| Original (do not modify) | `3db840dfeff4095d8508aa97`, workspace `468073bad9de0e9ca2287d8a`, element `8198d257a0b49b205e551477` |
| Working copy (edit this) | `00b1e7c9d07aec2789568fab`, workspace `f48449999f7a6cf5db9ca973` |
| — element `top` (the lug work) | `c8988bf041b2bcfcdef1a5a4` |
| — element `Bottom` | `683c1e415929ccc1972183f3` |
| — element `button` | `549b45f983101a2bbf977db6` |
| — element `Assembly 1` | `1e37806a3e2b45bacbff18d4` (**empty** — no instances or mates) |

## Measured geometry

Taken 2026-08-22 with `measure` on the outer wall faces, superseding the
projections the first revision relied on.

| Quantity | Measured |
| --- | --- |
| Top shell | 79.00 x 34.00 x 7.10mm |
| Bottom shell | 75.00 x 30.00 x 5.10mm |
| Wall thickness, all round | 2.0mm |
| Top shell z extent | −4.00 (skirt underside) to +3.10 (display face) |

The shell is a solid top plate from z = 0 to +3.10 across the whole footprint,
and a 2.0mm skirt wall from z = −4.00 to 0 enclosing the cavity the bottom
shell nests in. That split matters: material may be added freely in the plate,
but only as a wall band in the skirt.

No cavity breach, no gasket groove, no sealing land — this is not a sealed
design, so no seal-clearance constraint applies.

## As built

One parametric FeatureScript feature, `Watch lugs` (`FQvyVICWet8aFQF_2`),
followed by `Lug edge chamfers` (`FnRpLXh3nNIcqTZ_3`). The original tree is
untouched ahead of them; rolling back past both yields the previous case
exactly.

| Dimension | Value | Why |
| --- | --- | --- |
| Band width | 20mm | See below |
| Lug gap, inner face to inner face | 20.2mm (**verified**) | 20mm strap plus 0.2mm so it slides rather than wedges |
| Horn thickness, each | 6.9mm | Outer faces flush with the side walls at x = −12 and x = +22 |
| Total across the lugs | 34.00mm | Full case width — no shoulder |
| Spring bar bore | 1.1mm diameter, through, **teardrop** | Standard bar: 1.78mm body, ~0.9mm tips |
| Teardrop apex | Toward the part underside (−Z) | Self-supporting crown — see below |
| Bar standoff from body | 4.5mm | ~3.6mm clear gap to the bar surface, for thick bands |
| Horn protrusion | 6.5mm | Standoff plus 2.0mm of material past the bore |
| Lug-to-lug | 92.00mm (**verified**) | 79.00mm case plus 6.5mm each end |
| Tip chamfer | 0.5mm | On the horn-tip vertical edges |

Volume 9505.9mm³, one solid body.

### Decisions

**20mm band width.** The first revision chose 22mm on the strength of a
projected ~43mm-wide case leaving ~7mm of shoulder outboard of each horn. The
end measures 34.00mm, which triggered this spec's own stated fallback — *"20mm
is the fallback if the measured end is narrower than projected."*

**Horns flush with the side walls**, over a 3.5mm horn inset from the end. The
inset version left the horns rooting into the case's corner radii rather than
into solid end material, which read as thin tabs stuck on and produced eleven
sliver faces. Running the horns out to the side walls gives each one 6.9mm of
root across its full thickness and removes the shoulder entirely.

**Square end corners**, over rounded, and the chamfered "chop" at the +Y/−X
corner is gone. With flush horns the side walls now run straight from the body
through to the horn tips, so a corner radius would only reintroduce a step
where the horn meets the wall.

**Through-drilled bores**, over blind. A 1.1mm blind hole in an FDM side wall
prints badly, and a through-hole lets the bar be seated and released with a
paperclip instead of a spring-bar tool.

**Teardrop bores**, over round. The bore axis is horizontal when the case is
printed flat, so a round hole puts an unsupported crown at the top of the
circle, which sags and closes the hole up. The teardrop replaces that crown
with two flanks tangent to the bore at 45° meeting at an apex — the apex sits
r√2 from the centre, so at 1.1mm bore it extends the profile 0.23mm.

The apex points to the part's **underside** (−Z). That is only self-supporting
if the underside faces up on the bed, i.e. the case is printed display-side
down — which is also the orientation that puts the flat display face against
the bed. `teardropDown` flips it if the case is ever printed skirt-down
instead.

The 0.23mm of extra profile is in Z, while band tension pulls in ±Y, so the bar
tip still bears on the round part of the bore and the teardrop does not let it
shift under load.

**The counter of the "4" is deleted.** It was a fully disconnected solid —
the part carried two bodies, and the second was that island. It has no
support and would drop off the plate.

### Parameters

Editable on the `Watch lugs` feature; the geometry follows automatically.

| Parameter | Default |
| --- | --- |
| `bandWidth` | 20mm |
| `barStandoff` | 4.5mm |
| `tipMargin` | 2mm |
| `barHoleDia` | 1.1mm |
| `teardropDown` | true — apex toward the part underside |

Horn thickness is derived, not a parameter: the horns always run from the band
gap out to the side walls, so changing `bandWidth` rethickens them. Valid band
range is roughly 12–28mm before the horns get thinner than the walls or the
gap runs past them.

## Lug-to-lug length, for confirmation before printing

At 6.5mm of horn per end the 79.00mm case gives **92.00mm lug-to-lug**.

The first revision set a "stop if it exceeds ~58mm" threshold, derived from the
48–56mm range large *watches* occupy. That came in with the Watchy case import
and does not govern this product: a 79mm case cannot produce a 58mm span by any
arrangement of horns, and its length is not something the lugs can change. The
horns contribute 13mm of the 92mm; the rest is the device.

The open question is orientation, not horn length. The 79mm axis must run along
the forearm, since 79mm will not span a wrist — which makes lugs on the two
34mm ends the only sensible placement. **Confirm the device is worn
long-axis-along-the-arm before printing a full case.**

## Load path

Band tension pulls the horn, and through it the end wall, along the case's long
axis. That loads the wall in its own plane, where tension is not the limiting
mode. The limiting mode is the strap levering a horn up and down, which a
spring bar seated in a through-hole constrains. With flush horns the root is
6.9mm wide and 7.1mm tall, and the bore leaves 5.8mm of material across it.

## Print orientation

Printed with the case flat, layers stack in Z and strap tension pulls along the
layers rather than across them — the strong direction.

## Verification

Done: `describe_part_studio` topology checks after each feature; `measure`
confirming the 20.2mm gap and the 92.00mm lug-to-lug; a bottom render
confirming the skirt cavity is unbreached.

Outstanding: a printed single-end test piece with a real spring bar and strap
before committing to a full case print. Software confirms the geometry is
closed and printable; it cannot confirm the horns survive a wrist.

Known cosmetic note: a handful of sub-0.06mm² sliver faces remain where the new
prismatic geometry meets the original drafted and filleted walls. They are far
below FDM resolution, but check the STL export loads cleanly.

## Session notes

**Onshape authentication.** Access was confirmed working 2026-08-22 via
`list_documents`. The MCP server reads keys once at import from
`load_dotenv(os.path.join(_package_dir, ".env"))` — `onshape_mcp/server.py:19`
— where `_package_dir` is the version-pinned plugin root. A plugin update past
1.2.0 creates a new directory and the symlink must be remade; exports in
`~/.profile` avoid that. The residual failure mode is a stale server process:
the server belongs to the session that spawned it, so restarting the app
resumes the session without respawning it and credentials never load. A new
conversation fixes it.

**`create_extrude` and `create_offset_plane` are unusable on this document.**
Both return HTTP 400 from the features endpoint before Onshape evaluates
anything, for every argument combination tried — bare-number and unit-string
depths, NEW and ADD, with and without optional parameters, and with required
parameters only. `create_sketch` on the same Part Studio succeeds, so
credentials and the element id are fine; the common factor in the failures is
a quantity parameter in the payload. Everything here was therefore built with
`write_featurescript_feature`, which works. Do not spend another session
debugging the primitives — go straight to FeatureScript on this document.

**The account is at the Onshape free-tier 10-document cap**, so
`create_document` returns 409 and scratch/probe documents are not available for
diagnosis.

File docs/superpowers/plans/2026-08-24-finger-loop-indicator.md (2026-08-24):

# Finger-Loop Down Indicator Implementation Plan

> **For agentic workers:** REQUIRED SUB-SKILL: Use superpowers:subagent-driven-development (recommended) or superpowers:executing-plans to implement this plan task-by-task. Steps use checkbox (`- [ ]`) syntax for tracking.

**Goal:** Build a parametric OpenSCAD model of a wrist-worn body that anchors a bungee cord in two side-loading 7mm slots and mounts on a 20mm spring-bar watch strap.

**Architecture:** One top-level `.scad` file holds every tunable parameter and the assembly; `lib/` holds pure modules that take their dimensions as arguments and read no globals, so each can be rendered standalone by a test harness. Correctness is asserted against the rendered mesh — `openscad` exports STL, `trimesh` loads it, and tests check watertightness, bounding box, exact volume and point-containment probes. Parameter combinations that would produce an unbuildable part are rejected by `assert()` inside the model rather than by a test.

**Tech Stack:** OpenSCAD 2021.01 (already installed at `/usr/bin/openscad`), Python 3.13, `trimesh` 5.0.0, `numpy`, `scipy`, `rtree`, `pytest` 9.1.1, GNU make.

**Spec:** [2026-08-24-finger-loop-indicator-design.md](../../../2026-08-24-finger-loop-indicator-design.md)

## Global Constraints

- All work lives in a new `down-indicator/` directory at the repository root. Nothing outside it changes except `README.md` (Task 6) and a new root `.gitignore` (Task 1).
- Coordinates: **+X across the wrist, +Y along the forearm toward the hand, +Z out of the watch face.** The body spans z = 0 (wrist side) to z = `bodyT` (face). Every module and test uses this frame.
- Every `lib/*.scad` module takes its dimensions as **explicit arguments**. No module reads a global. This is what lets the test harnesses render one module in isolation.
- All parameters are declared at the top level of `down_indicator.scad` so `openscad -D name=value` can override them. `use <>` does not import variables, so this is the only file where parameters live.
- `$fn = 96` everywhere, including in the test harness `.scad` files. Volume assertions are exact to the facet count and will fail if it differs.
- **OpenSCAD infers output format from the file extension.** `-o /dev/null` fails with exit code 1 regardless of the model. Always render to a real `.stl` path, including when you only care about whether the render succeeded.
- Dimensions, verbatim from the spec: `bodyLen = 40.0`, `bodyWid = 30.0`, `bodyT = 6.7`, `cordDia = 7.0`, `holeY = 10.0`, `bandWidth = 20.0`, `bandClear = 0.2`, `barStandoff = 4.5`, `tipMargin = 2.0`, `barHoleDia = 1.1`, `tipChamfer = 0.5`, `teardropDown = true`.
- Commit at the end of every task. Do not amend or squash earlier tasks' commits.

## File Structure

| File | Responsibility |
| --- | --- |
| `down-indicator/down_indicator.scad` | Every parameter, the derived values, the `assert()` guards, and the assembly. The only file with globals. |
| `down-indicator/lib/util.scad` | `teardrop_2d`, `teardrop_bore`. Shared by nothing else today; kept separate because the teardrop is the one non-obvious profile in the model. |
| `down-indicator/lib/body.scad` | `body_blank` — the bare slab. |
| `down-indicator/lib/cord_slots.scad` | `cord_cutter`, `cord_trough` — the subtractive tool for the holes and the face troughs. |
| `down-indicator/lib/lugs.scad` | `lug_horns` (additive), `horn_profile`, `bar_bores` (subtractive). |
| `down-indicator/tests/conftest.py` | `render()` and `render_failure()` — run OpenSCAD, cache by source-content hash, return a `trimesh` mesh. Plus the `inside()` probe helper and the shared fixtures. |
| `down-indicator/tests/scad/*.scad` | One tiny harness per lib module, so a module can be rendered without the rest of the assembly. |
| `down-indicator/tests/test_body.py` | Task 1 |
| `down-indicator/tests/test_cord_slots.py` | Tasks 2 and 3 |
| `down-indicator/tests/test_lugs.py` | Tasks 4 and 5 |
| `down-indicator/tests/test_assembly.py` | Task 6 — the whole part and the parameter guards |
| `down-indicator/Makefile` | `make test`, `make stl`, `make clean` |
| `down-indicator/requirements.txt` | Pinned Python dependencies |
| `down-indicator/README.md` | Task 6 |

---

### Task 1: Scaffold, render harness, and the body blank

Sets up the venv, the OpenSCAD-to-trimesh bridge every later task depends on, and the simplest possible piece of geometry to prove the bridge works end to end.

**Files:**
- Create: `down-indicator/lib/body.scad`
- Create: `down-indicator/tests/conftest.py`
- Create: `down-indicator/tests/scad/body_only.scad`
- Create: `down-indicator/tests/test_body.py`
- Create: `down-indicator/Makefile`
- Create: `down-indicator/requirements.txt`
- Create: `.gitignore` (repository root)

**Interfaces:**
- Consumes: nothing.
- Produces:
  - `body_blank(len, wid, t)` — a solid slab `wid` in X by `len` in Y by `t` in Z, centred on the origin in X and Y, sitting on z = 0.
  - `render(scad_relpath, **overrides) -> trimesh.Trimesh` — renders a `.scad` file under `down-indicator/` and returns the mesh. Keyword overrides become `-D name=value`; Python `bool` is emitted as OpenSCAD `true`/`false`.
  - `render_failure(scad_relpath, **overrides) -> str` — asserts the render fails and returns combined stdout+stderr.
  - `inside(mesh, *points) -> numpy.ndarray[bool]` — point containment, one bool per point.

- [ ] **Step 1: Create the directory and pin the dependencies**

```bash
mkdir -p down-indicator/lib down-indicator/tests/scad
```

`down-indicator/requirements.txt`:

```
trimesh==5.0.0
numpy==2.5.2
scipy==1.18.1
rtree==1.4.1
pytest==9.1.1
```

`scipy` and `rtree` are not optional: `trimesh` degrades silently without them and then raises `ModuleNotFoundError` from inside `body_count` and `contains`, which are the two checks this suite leans on hardest.

Root `.gitignore`:

```
build/
.venv/
__pycache__/
.pytest_cache/
*.pyc
```

- [ ] **Step 2: Write the Makefile**

`down-indicator/Makefile`:

```make
OPENSCAD ?= openscad
VENV     := .venv

.PHONY: test stl clean

$(VENV): requirements.txt
	python3 -m venv $(VENV)
	$(VENV)/bin/pip install -q -r requirements.txt
	touch $(VENV)

test: $(VENV)
	$(VENV)/bin/pytest -q

stl: build/down_indicator.stl

build/down_indicator.stl: down_indicator.scad $(wildcard lib/*.scad)
	@mkdir -p build
	$(OPENSCAD) -o $@ $<

clean:
	rm -rf build
```

- [ ] **Step 3: Write the render harness**

`down-indicator/tests/conftest.py`:

```python
"""Render OpenSCAD models to meshes so tests can assert against real geometry.

Renders are cached on a hash of every .scad file in the project, so a suite
that renders the same model from several tests pays the CGAL cost once, and
editing any model file invalidates the cache.
"""

import hashlib
import os
import subprocess
from pathlib import Path

import numpy as np
import pytest
import trimesh

ROOT = Path(__file__).resolve().parents[1]
BUILD = ROOT / "build" / "test"
OPENSCAD = os.environ.get("OPENSCAD", "openscad")

def _sources_key() -> str:
    digest = hashlib.sha1()
    for path in sorted(ROOT.rglob("*.scad")):
        digest.update(path.read_bytes())
    return digest.hexdigest()[:16]

def _defines(overrides: dict) -> list:
    out = []
    for key in sorted(overrides):
        value = overrides[key]
        if isinstance(value, bool):
            value = "true" if value else "false"
        out += ["-D", f"{key}={value}"]
    return out

def _run(scad_relpath: str, out_path: Path, overrides: dict):
    return subprocess.run(
        [OPENSCAD, "-o", str(out_path), *_defines(overrides), str(ROOT / scad_relpath)],
        capture_output=True,
        text=True,
    )

def render(scad_relpath: str, **overrides) -> trimesh.Trimesh:
    """Render a model and return it as a mesh. Fails the test if OpenSCAD does."""
    defines = _defines(overrides)
    key = hashlib.sha1(
        f"{scad_relpath}|{defines}|{_sources_key()}".encode()
    ).hexdigest()[:16]
    BUILD.mkdir(parents=True, exist_ok=True)
    out_path = BUILD / f"{key}.stl"
    if not out_path.exists():
        proc = _run(scad_relpath, out_path, overrides)
        if proc.returncode != 0 or not out_path.exists():
            pytest.fail(
                f"OpenSCAD failed on {scad_relpath} {defines}\n"
                f"{proc.stdout}\n{proc.stderr}"
            )
    return trimesh.load(out_path, force="mesh")

def render_failure(scad_relpath: str, **overrides) -> str:
    """Assert the render is rejected, and return what OpenSCAD said about it."""
    BUILD.mkdir(parents=True, exist_ok=True)
    out_path = BUILD / "rejected.stl"
    out_path.unlink(missing_ok=True)
    proc = _run(scad_relpath, out_path, overrides)
    assert proc.returncode != 0, (
        f"expected {scad_relpath} {overrides} to be rejected, but it rendered"
    )
    return proc.stdout + proc.stderr

def inside(mesh, *points) -> np.ndarray:
    """True for each point that lies inside the solid."""
    return mesh.contains(np.array(points, dtype=float))

@pytest.fixture(scope="session")
def blank():
    return render("tests/scad/body_only.scad")
```

- [ ] **Step 4: Write the failing test**

`down-indicator/tests/test_body.py`:

```python
"""The bare slab: 30mm across the wrist, 40mm along the forearm, 6.7mm thick."""

from pytest import approx

def test_blank_is_one_closed_solid(blank):
    assert blank.is_watertight
    assert blank.is_winding_consistent
    assert blank.body_count == 1

def test_blank_bounding_box(blank):
    low, high = blank.bounds
    assert list(low) == approx([-15.0, -20.0, 0.0], abs=1e-6)
    assert list(high) == approx([15.0, 20.0, 6.7], abs=1e-6)

def test_blank_volume_is_the_full_prism(blank):
    assert blank.volume == approx(30.0 * 40.0 * 6.7, rel=1e-9)

def test_blank_sits_on_the_bed_and_is_solid_through(blank):
    from conftest import inside

    assert inside(blank, [0, 0, 0.1], [0, 0, 3.35], [0, 0, 6.6]).all()
    assert not inside(blank, [0, 0, -0.1], [0, 0, 6.8]).any()
```

- [ ] **Step 5: Run the test to verify it fails**

```bash
cd down-indicator && make test
```

Expected: FAIL. `body_only.scad` and `body.scad` do not exist yet, so `render` calls `pytest.fail` with OpenSCAD's "Can't open input file" error.

- [ ] **Step 6: Write the model**

`down-indicator/lib/body.scad`:

```openscad
// The bare case body.
//
// A plain rectangular slab, square in plan. The lug horns run flush to the
// side walls, so a corner radius here would root them into the radius rather
// than into solid end material -- the failure the down counter's lug spec
// diagnosed and fixed by squaring the corners.

// `wid` across X, `len` along Y, centred on the origin in plan, sitting on z = 0.
module body_blank(len, wid, t) {
    linear_extrude(height = t) square([wid, len], center = true);
}
```

`down-indicator/tests/scad/body_only.scad`:

```openscad
use <../../lib/body.scad>

bodyLen = 40.0;
bodyWid = 30.0;
bodyT   =  6.7;
$fn = 96;

body_blank(bodyLen, bodyWid, bodyT);
```

- [ ] **Step 7: Run the test to verify it passes**

```bash
cd down-indicator && make test
```

Expected: PASS, 4 tests. The first run also builds `.venv`, which takes about a minute.

- [ ] **Step 8: Commit**

```bash
git add .gitignore down-indicator/
git commit -m "feat(down-indicator): scaffold OpenSCAD project and body blank"
```

---

### Task 2: Cord holes

Two 7mm through-bores on the Y centreline. Split from the troughs because the holes alone are a clean, exactly-computable volume, and getting that number right proves the subtractive path before the harder geometry lands on top of it.

**Files:**
- Create: `down-indicator/lib/cord_slots.scad`
- Create: `down-indicator/tests/scad/cord_only.scad`
- Create: `down-indicator/tests/test_cord_slots.py`
- Modify: `down-indicator/tests/conftest.py` (add the `cord` fixture)

**Interfaces:**
- Consumes: `body_blank(len, wid, t)` from Task 1.
- Produces: `cord_cutter(len, t, dia, holeY)` — the full subtractive tool for holes and troughs, positioned in the body's own frame and intended to be passed to `difference()`. This task implements the holes only; Task 3 adds the troughs to the same module without changing its signature.

- [ ] **Step 1: Add the fixture**

Append to `down-indicator/tests/conftest.py`:

```python
@pytest.fixture(scope="session")
def cord():
    return render("tests/scad/cord_only.scad")
```

- [ ] **Step 2: Write the failing test**

`down-indicator/tests/test_cord_slots.py`:

```python
"""The cord holes and the face troughs that open them to the ends."""

import math

import numpy as np
from pytest import approx

from conftest import inside

BODY_T = 6.7
CORD_R = 3.5
MID = BODY_T / 2
BLANK_VOLUME = 30.0 * 40.0 * 6.7

# A 96-gon inscribed in a circle of radius r has area 48 * r^2 * sin(3.75 deg).
HOLE_AREA = 0.5 * 96 * CORD_R**2 * math.sin(math.radians(360 / 96))

def test_cord_body_is_one_closed_solid(cord):
    assert cord.is_watertight
    assert cord.body_count == 1

def test_holes_remove_exactly_two_cylinders(cord):
    assert BLANK_VOLUME - cord.volume == approx(2 * HOLE_AREA * BODY_T, rel=1e-6)

def test_each_hole_goes_all_the_way_through(cord):
    for sign in (-1, 1):
        column = [[0.0, sign * 10.0, z] for z in (0.2, MID, 6.5)]
        assert not inside(cord, *column).any()

def test_holes_are_seven_millimetres_across(cord):
    # Probe across the +Y hole at mid-height, 0.1mm inside and outside the wall.
    assert not inside(cord, [3.4, 10.0, MID])[0]
    assert inside(cord, [3.6, 10.0, MID])[0]

def test_material_remains_between_the_holes(cord):
    assert inside(cord, [0.0, 0.0, MID])[0]
```

- [ ] **Step 3: Run the test to verify it fails**

```bash
cd down-indicator && .venv/bin/pytest tests/test_cord_slots.py -q
```

Expected: FAIL — `cord_only.scad` does not exist, so every test fails in the fixture with OpenSCAD's "Can't open input file".

- [ ] **Step 4: Write the model**

`down-indicator/lib/cord_slots.scad`:

```openscad
// The cord holes and the face troughs that open them to the ends.
//
// Everything here is a cutting tool, meant for the negative half of a
// difference() against the body.

// Two through-bores of diameter `dia`, on the Y centreline at +-holeY.
module cord_cutter(len, t, dia, holeY) {
    for (s = [-1, 1])
        translate([0, s * holeY, -1]) cylinder(h = t + 2, d = dia);
}
```

`down-indicator/tests/scad/cord_only.scad`:

```openscad
use <../../lib/body.scad>
use <../../lib/cord_slots.scad>

bodyLen = 40.0;
bodyWid = 30.0;
bodyT   =  6.7;
cordDia =  7.0;
holeY   = 10.0;
$fn = 96;

difference() {
    body_blank(bodyLen, bodyWid, bodyT);
    cord_cutter(bodyLen, bodyT, cordDia, holeY);
}
```

- [ ] **Step 5: Run the test to verify it passes**

```bash
cd down-indicator && make test
```

Expected: PASS, 9 tests. `cord.volume` is 7524.6756mm³; the removed 515.3244mm³ matches the closed form to six significant figures.

- [ ] **Step 6: Commit**

```bash
git add down-indicator/
git commit -m "feat(down-indicator): add the two 7mm cord holes"
```

---

### Task 3: Cord slot troughs

The heart of the part. A trough of the same 7mm diameter is cut into the watch face and into the wrist side, running from each hole out to the body end. Because the body is thinner than the trough diameter the two overlap at mid-thickness, leaving a slot the cord presses into from the side.

**Files:**
- Modify: `down-indicator/lib/cord_slots.scad`
- Modify: `down-indicator/tests/test_cord_slots.py`

**Interfaces:**
- Consumes: `cord_cutter(len, t, dia, holeY)` from Task 2.
- Produces: `cord_trough(len, t, dia, holeY, s)` — one face-pair of troughs for the hole on side `s` (`+1` for the +Y hole, `-1` for the −Y hole), running from that hole's centre out past the end face. Called by `cord_cutter`, which keeps its Task 2 signature.

- [ ] **Step 1: Retire the superseded hole-volume test**

Delete `test_holes_remove_exactly_two_cylinders` from `down-indicator/tests/test_cord_slots.py`, and delete the now-unused `HOLE_AREA` constant and the `import math`-dependent comment above it. Keep `import math` — the neck arithmetic below needs it.

That test asserts `BLANK_VOLUME - cord.volume == 515.3244`. This task adds troughs to the same `cord_cutter`, so the figure becomes 1050.79 and the two assertions contradict each other. After this task the holes are no longer a separable feature of `cord_cutter`, so the hole-only volume cannot be observed from the `cord_only` harness without duplicating cylinder geometry into a second harness. `test_holes_and_troughs_together` below carries the combined closed-form check forward; `test_holes_are_seven_millimetres_across` and `test_each_hole_goes_all_the_way_through` keep pinning hole geometry directly and both still pass once the troughs exist.

- [ ] **Step 2: Write the failing test**

Append to `down-indicator/tests/test_cord_slots.py`:

```python
# Where the two face troughs overlap, at mid-thickness:
#   neck = 2 * sqrt(r^2 - (t/2)^2) = 2.0273mm
NECK = 2 * math.sqrt(CORD_R**2 - (BODY_T / 2) ** 2)

def test_the_arithmetic_the_thickness_was_chosen_for():
    assert NECK == approx(2.027, abs=0.001)

def test_the_slot_is_open_from_the_hole_to_the_end(cord):
    """No solid anywhere on the slot centreline at mid-thickness."""
    for sign in (-1, 1):
        ys = np.linspace(sign * 10.0, sign * 20.0, 41)
        points = [[0.0, y, MID] for y in ys]
        assert not inside(cord, *points).any()

def test_the_neck_is_the_width_the_geometry_predicts(cord):
    y = 16.0  # midway between the hole edge and the body end
    assert not inside(cord, [NECK / 2 - 0.1, y, MID])[0], "neck is narrower than predicted"
    assert inside(cord, [NECK / 2 + 0.1, y, MID])[0], "neck is wider than predicted"

def test_the_trough_is_full_width_at_both_faces(cord):
    y = 16.0
    for z in (0.05, BODY_T - 0.05):
        assert not inside(cord, [3.3, y, z])[0], "trough is not 7mm wide at the face"
        assert inside(cord, [3.7, y, z])[0], "trough is wider than 7mm at the face"

def test_the_troughs_run_outward_not_inward(cord):
    """Between the two holes the body is untouched at every height."""
    for z in (0.05, MID, BODY_T - 0.05):
        assert inside(cord, [0.0, 0.0, z])[0]

def test_holes_and_troughs_together(cord):
    assert cord.volume == approx(6989.209, rel=1e-4)
    assert cord.is_watertight
    assert cord.body_count == 1
```

- [ ] **Step 3: Run the test to verify it fails**

```bash
cd down-indicator && .venv/bin/pytest tests/test_cord_slots.py -q
```

Expected: FAIL. `test_the_arithmetic_the_thickness_was_chosen_for` passes (it is pure arithmetic), and the five geometry tests fail — the slot centreline is solid, so `test_the_slot_is_open_from_the_hole_to_the_end` fails first.

- [ ] **Step 4: Write the model**

Replace the contents of `down-indicator/lib/cord_slots.scad`:

```openscad
// The cord holes and the face troughs that open them to the ends.
//
// Everything here is a cutting tool, meant for the negative half of a
// difference() against the body.
//
// Each hole is a through-bore of diameter `dia`. From each hole a trough of
// the same diameter runs outward along Y, cut into the watch face (axis at
// z = t) and into the wrist side (axis at z = 0). Because t < dia the two
// troughs overlap at mid-thickness, so the slot is open end to end and the
// cord presses in from the side rather than being threaded.
//
// The neck left at mid-thickness is 2 * sqrt((dia/2)^2 - (t/2)^2); at
// dia = 7.0 and t = 6.7 that is 2.027mm. The caller is responsible for
// asserting t < dia -- at t == dia the troughs meet along a knife edge and
// the slot has zero width.

module cord_cutter(len, t, dia, holeY) {
    for (s = [-1, 1]) {
        translate([0, s * holeY, -1]) cylinder(h = t + 2, d = dia);
        cord_trough(len, t, dia, holeY, s);
    }
}

// One face-pair of troughs, for the hole on side `s`. Runs from the hole
// centre out to 1mm past the end face, so the slot exits cleanly.
module cord_trough(len, t, dia, holeY, s) {
    run = len / 2 + 1 - holeY;
    for (z = [0, t])
        translate([0, s * holeY, z])
            rotate([-90 * s, 0, 0])
                cylinder(h = run, d = dia);
}
```

`rotate([-90 * s, 0, 0])` turns the cylinder's +Z axis into +Y for `s = 1` and into −Y for `s = -1`, so each hole's troughs run toward its own end of the body.

- [ ] **Step 5: Run the test to verify it passes**

```bash
cd down-indicator && make test
```

Expected: PASS, 14 tests (the retired hole-volume test brings the file to 10).

- [ ] **Step 6: Commit**

```bash
git add down-indicator/
git commit -m "feat(down-indicator): open the cord holes to the ends with face troughs"
```

---

### Task 4: Spring-bar lug horns

The additive half of the band mount: four horns, flush with the side walls, protruding 6.5mm past each end. Geometry carried over from the down counter's lug spec, with horn thickness re-derived for a 30mm end.

**Files:**
- Create: `down-indicator/lib/lugs.scad`
- Create: `down-indicator/tests/scad/lugs_only.scad`
- Create: `down-indicator/tests/test_lugs.py`
- Modify: `down-indicator/tests/conftest.py` (add the `lugs` fixture)

Probe solid horn material at `HORN_Y = 22.0`, never at `BAR_Y = 24.5`. Task 5 drills a bore straight along X at `BAR_Y` and `z = t/2`, so any "this should be solid" probe placed there passes now and starts failing the moment the bores land.

**Interfaces:**
- Consumes: `body_blank(len, wid, t)` from Task 1.
- Produces: `lug_horns(len, wid, t, gap, prot, tipCham)` — four additive horns; `horn_profile(thk, prot, cham, sy)` — the plan-view outline of one horn, with its far-end corners chamfered, pointing in the `sy` direction.

- [ ] **Step 1: Add the fixture**

Append to `down-indicator/tests/conftest.py`:

```python
@pytest.fixture(scope="session")
def lugs():
    return render("tests/scad/lugs_only.scad")
```

- [ ] **Step 2: Write the failing test**

`down-indicator/tests/test_lugs.py`:

```python
"""Spring-bar lugs, carried over from the down counter's as-built geometry."""

from pytest import approx

from conftest import inside

BODY_T = 6.7
MID = BODY_T / 2
GAP = 20.2          # 20mm band + 0.2mm clearance
HORN_THK = 4.9      # (30 - 20.2) / 2
PROT = 6.5          # 4.5mm bar standoff + 2.0mm tip margin
BAR_Y = 24.5        # 20 + 4.5, where Task 5 drills the bore
HORN_Y = 22.0       # solid horn, clear of the bore -- probe material here
BLANK_VOLUME = 30.0 * 40.0 * 6.7

def test_lug_body_is_one_closed_solid(lugs):
    assert lugs.is_watertight
    assert lugs.body_count == 1

def test_lug_to_lug_is_fifty_three_millimetres(lugs):
    low, high = lugs.bounds
    assert high[1] - low[1] == approx(53.0, abs=1e-6)
    assert list(low) == approx([-15.0, -26.5, 0.0], abs=1e-6)
    assert list(high) == approx([15.0, 26.5, 6.7], abs=1e-6)

def test_horns_add_four_chamfered_prisms(lugs):
    # 4 horns, less a 0.5mm chamfer on each of the two tip corners per horn.
    expected = 4 * HORN_THK * PROT * BODY_T - 4 * 2 * (0.5 * 0.5**2) * BODY_T
    assert lugs.volume - BLANK_VOLUME == approx(expected, rel=1e-6)

def test_the_band_gap_takes_a_twenty_millimetre_strap(lugs):
    # Open across the full gap...
    assert not inside(lugs, [0.0, HORN_Y, MID], [10.0, HORN_Y, MID], [-10.0, HORN_Y, MID]).any()
    # ...and solid immediately outboard of it.
    assert inside(lugs, [10.3, HORN_Y, MID], [-10.3, HORN_Y, MID]).all()

def test_horns_run_flush_to_the_side_walls(lugs):
    assert inside(lugs, [14.8, HORN_Y, MID])[0]
    assert not inside(lugs, [15.2, HORN_Y, MID])[0]

def test_horns_are_full_body_height(lugs):
    assert inside(lugs, [12.5, HORN_Y, 0.1], [12.5, HORN_Y, BODY_T - 0.1]).all()
    assert not inside(lugs, [12.5, HORN_Y, -0.1], [12.5, HORN_Y, BODY_T + 0.1]).any()

def test_tip_corners_are_chamfered(lugs):
    # The outboard tip corner at (15, 26.5) is cut back by 0.5mm.
    assert not inside(lugs, [14.9, 26.4, MID])[0]
    assert inside(lugs, [14.3, 26.4, MID])[0]
```

- [ ] **Step 3: Run the test to verify it fails**

```bash
cd down-indicator && .venv/bin/pytest tests/test_lugs.py -q
```

Expected: FAIL, 7 tests — `lugs_only.scad` does not exist.

- [ ] **Step 4: Write the model**

`down-indicator/lib/lugs.scad`:

```openscad
// Spring-bar lugs, carried over from the down counter's as-built geometry
// (see 2026-08-22-band-lugs-design.md): horns flush with the side walls,
// squared roots, 0.5mm tip chamfers.
//
// Horn thickness is derived, not a parameter -- the horns always run from the
// band gap out to the side walls, so widening the band thins them.

// Four horns, one at each corner, protruding `prot` past each end face.
module lug_horns(len, wid, t, gap, prot, tipCham) {
    hornThk = (wid - gap) / 2;
    ol = 0.5;   // root overlap into the body, so the union is not face-coincident
    for (sy = [-1, 1], sx = [-1, 1])
        translate([sx * (gap / 2 + hornThk / 2),
                   sy * (len / 2 - ol / 2 + prot / 2),
                   0])
            linear_extrude(height = t)
                horn_profile(hornThk, prot + ol, tipCham, sy);
}

// Plan-view outline of one horn: a thk x prot rectangle whose two far-end
// corners are chamfered by `cham`. `sy` selects which end is the tip.
module horn_profile(thk, prot, cham, sy) {
    y0 = -sy * prot / 2;   // rooted end
    y1 =  sy * prot / 2;   // tip end
    polygon([
        [-thk / 2,        y0],
        [ thk / 2,        y0],
        [ thk / 2,        y1 - sy * cham],
        [ thk / 2 - cham, y1],
        [-thk / 2 + cham, y1],
        [-thk / 2,        y1 - sy * cham],
    ]);
}
```

The 0.5mm root overlap matters: butting the horn's root face exactly against the body's end face gives CGAL two coincident planes to union, which is a well-known source of non-manifold output. Overlapping is free — the extra material is inside the body.

`down-indicator/tests/scad/lugs_only.scad`:

```openscad
use <../../lib/body.scad>
use <../../lib/lugs.scad>

bodyLen    = 40.0;
bodyWid    = 30.0;
bodyT      =  6.7;
lugGap     = 20.2;
hornProt   =  6.5;
tipChamfer =  0.5;
$fn = 96;

union() {
    body_blank(bodyLen, bodyWid, bodyT);
    lug_horns(bodyLen, bodyWid, bodyT, lugGap, hornProt, tipChamfer);
}
```

- [ ] **Step 5: Run the test to verify it passes**

```bash
cd down-indicator && make test
```

Expected: PASS, 21 tests. `lugs.volume` is 8886.88mm³, exactly 846.88mm³ over the blank.

- [ ] **Step 6: Commit**

```bash
git add down-indicator/
git commit -m "feat(down-indicator): add 20mm spring-bar lug horns"
```

---

### Task 5: Teardrop spring-bar bores

The subtractive half of the band mount. The bore axis is horizontal when the case prints flat, so a round hole would put an unsupported crown at the top of the circle. The teardrop replaces it with two flanks tangent at 45 degrees, apex toward −Z.

**Files:**
- Create: `down-indicator/lib/util.scad`
- Modify: `down-indicator/lib/lugs.scad`
- Modify: `down-indicator/tests/scad/lugs_only.scad`
- Modify: `down-indicator/tests/test_lugs.py`

**Interfaces:**
- Consumes: `lug_horns(...)` from Task 4.
- Produces:
  - `teardrop_2d(r)` — a 2D circle of radius `r` with a self-supporting apex at `(0, r * sqrt(2))`.
  - `teardrop_bore(d, h)` — that profile extruded `h` along +Z, apex toward +Y in the local frame.
  - `bar_bores(len, wid, t, gap, standoff, dia, apexDown)` — four bores, one per horn, run along X at `y = ±(len/2 + standoff)` and `z = t/2`. Subtractive.

- [ ] **Step 1: Write the failing test**

Append to `down-indicator/tests/test_lugs.py`:

```python
BAR_R = 0.55        # 1.1mm bore
HORNS_VOLUME = 8886.88

def test_the_bore_runs_right_through_the_horn(lugs):
    row = [[x, BAR_Y, MID] for x in (10.5, 12.5, 14.5)]
    assert not inside(lugs, *row).any()

def test_the_bore_sits_at_mid_height_with_material_above_and_below(lugs):
    assert inside(lugs, [12.5, BAR_Y, MID + 1.5], [12.5, BAR_Y, MID - 1.5]).all()

def test_the_bore_is_offset_from_the_tip_by_the_margin(lugs):
    # 2mm of material past the bore centre, so the tip at y = 26.5 is solid.
    assert inside(lugs, [12.5, 26.2, MID])[0]

def test_the_teardrop_apex_points_toward_the_wrist_side(lugs):
    """Apex at r*sqrt(2) below centre; the matching point above is solid."""
    reach = BAR_R * 1.35   # inside r*sqrt(2) = 0.778, outside r = 0.55
    assert not inside(lugs, [12.5, BAR_Y, MID - reach])[0], "no apex on the -Z side"
    assert inside(lugs, [12.5, BAR_Y, MID + reach])[0], "apex is on the wrong side"

def test_bores_remove_four_small_teardrops(lugs):
    # Teardrop area is r^2 * (3*pi/4 + 1); four bores through 4.9mm of horn.
    expected = 4 * (BAR_R**2 * (3 * math.pi / 4 + 1)) * HORN_THK
    assert HORNS_VOLUME - lugs.volume == approx(expected, rel=0.02)

def test_lug_body_is_still_one_closed_solid(lugs):
    assert lugs.is_watertight
    assert lugs.body_count == 1
```

Add `import math` to the top of the file alongside the existing imports.

`test_horns_add_four_chamfered_prisms` from Task 4 now measures a body that has bores in it and must be updated to subtract them. Replace it with:

```python
def test_horns_add_four_chamfered_prisms(lugs):
    # 4 horns, less a 0.5mm chamfer on each of the two tip corners per horn,
    # less the four bar bores.
    horns = 4 * HORN_THK * PROT * BODY_T - 4 * 2 * (0.5 * 0.5**2) * BODY_T
    bores = 4 * (BAR_R**2 * (3 * math.pi / 4 + 1)) * HORN_THK
    assert lugs.volume - BLANK_VOLUME == approx(horns - bores, rel=0.001)
```

- [ ] **Step 2: Run the test to verify it fails**

```bash
cd down-indicator && .venv/bin/pytest tests/test_lugs.py -q
```

Expected: FAIL, 6 of the new tests plus the rewritten volume test — the horns are still solid, so `test_the_bore_runs_right_through_the_horn` reports every probe inside the solid.

- [ ] **Step 3: Write the teardrop helper**

`down-indicator/lib/util.scad`:

```openscad
// Shared profiles.

// A circle of radius r with a self-supporting apex: two flanks tangent to the
// bore at 45 degrees, meeting r * sqrt(2) from the centre. Printed with the
// apex upward, it replaces the unsupported crown of a horizontal round hole.
// Apex toward +Y.
module teardrop_2d(r) {
    union() {
        circle(r = r);
        rotate([0, 0, 45]) square([r, r]);
    }
}

// That profile as a bore of diameter d and length h, extruded along +Z.
module teardrop_bore(d, h) {
    linear_extrude(height = h) teardrop_2d(d / 2);
}
```

The rotated square's two near corners land at `(±r/sqrt(2), r/sqrt(2))`, which lie exactly on the circle — that is what makes the flanks tangent rather than secant.

- [ ] **Step 4: Write the bores**

Add to the top of `down-indicator/lib/lugs.scad`:

```openscad
use <util.scad>
```

Append to `down-indicator/lib/lugs.scad`:

```openscad
// Spring-bar bores, one per horn, running along X at z = t/2 and
// y = +-(len/2 + standoff). Teardropped so the crown is self-supporting when
// the case prints face down; `apexDown` puts the apex toward the wrist side,
// which is the upward direction in that orientation.
module bar_bores(len, wid, t, gap, standoff, dia, apexDown) {
    hornThk = (wid - gap) / 2;
    for (sy = [-1, 1], sx = [-1, 1])
        translate([sx * (gap / 2 - 1), sy * (len / 2 + standoff), t / 2])
            rotate([0, sx * 90, 0])
                rotate([0, 0, (apexDown ? -90 : 90) * sx])
                    teardrop_bore(dia, hornThk + 2);
}
```

The two nested rotations do different jobs and the order matters. The inner one spins the teardrop within its own profile plane so the apex ends up along the local X axis; the outer one lays the bore axis down onto world X. Both are signed by `sx`, because mirroring the horn to the other side of the part also mirrors which way "apex down" turns out to be.

Update `down-indicator/tests/scad/lugs_only.scad` to subtract them:

```openscad
use <../../lib/body.scad>
use <../../lib/lugs.scad>

bodyLen      = 40.0;
bodyWid      = 30.0;
bodyT        =  6.7;
lugGap       = 20.2;
hornProt     =  6.5;
tipChamfer   =  0.5;
barStandoff  =  4.5;
barHoleDia   =  1.1;
teardropDown = true;
$fn = 96;

difference() {
    union() {
        body_blank(bodyLen, bodyWid, bodyT);
        lug_horns(bodyLen, bodyWid, bodyT, lugGap, hornProt, tipChamfer);
    }
    bar_bores(bodyLen, bodyWid, bodyT, lugGap, barStandoff, barHoleDia, teardropDown);
}
```

- [ ] **Step 5: Run the test to verify it passes**

```bash
cd down-indicator && make test
```

Expected: PASS, 27 tests. `lugs.volume` drops from 8886.88 to 8866.992mm³.

- [ ] **Step 6: Check the apex flips with the parameter**

Add to `down-indicator/tests/test_lugs.py`:

```python
def test_teardrop_can_be_flipped_for_the_other_print_orientation():
    from conftest import render

    flipped = render("tests/scad/lugs_only.scad", teardropDown=False)
    reach = BAR_R * 1.35
    assert not inside(flipped, [12.5, BAR_Y, MID + reach])[0]
    assert inside(flipped, [12.5, BAR_Y, MID - reach])[0]
```

Run it:

```bash
cd down-indicator && .venv/bin/pytest tests/test_lugs.py -q
```

Expected: PASS, 28 tests. This is also the first exercise of the `-D` override path, which Task 6 depends on entirely.

- [ ] **Step 7: Commit**

```bash
git add down-indicator/
git commit -m "feat(down-indicator): add teardrop spring-bar bores"
```

---

### Task 6: Assembly, parameter guards, and documentation

Brings the three subsystems together into the shipping model, adds the `assert()` guards that reject unbuildable parameter combinations, and documents the result.

**Files:**
- Create: `down-indicator/down_indicator.scad`
- Create: `down-indicator/tests/test_assembly.py`
- Create: `down-indicator/README.md`
- Modify: `down-indicator/tests/conftest.py` (add the `part` fixture)
- Modify: `README.md` (repository root)

**Interfaces:**
- Consumes: `body_blank`, `cord_cutter`, `lug_horns`, `bar_bores` — all as defined in Tasks 1–5, unchanged.
- Produces: `down_indicator()` — the complete part, and the top-level parameter block that `-D` overrides target.

- [ ] **Step 1: Add the fixture**

Append to `down-indicator/tests/conftest.py`:

```python
@pytest.fixture(scope="session")
def part():
    return render("down_indicator.scad")
```

- [ ] **Step 2: Write the failing test**

`down-indicator/tests/test_assembly.py`:

```python
"""The complete part, and the guards on its parameters."""

import math

from pytest import approx

from conftest import inside, render, render_failure

BODY_T = 6.7
MID = BODY_T / 2
NECK = 2 * math.sqrt(3.5**2 - (BODY_T / 2) ** 2)
BAR_Y = 24.5

def test_the_part_is_one_closed_printable_solid(part):
    assert part.is_watertight
    assert part.is_winding_consistent
    assert part.body_count == 1
    assert part.volume == approx(7816.2, rel=1e-4)

def test_overall_dimensions(part):
    low, high = part.bounds
    assert list(low) == approx([-15.0, -26.5, 0.0], abs=1e-6)
    assert list(high) == approx([15.0, 26.5, 6.7], abs=1e-6)

def test_the_cord_slots_survive_the_assembly(part):
    for sign in (-1, 1):
        run = [[0.0, sign * y, MID] for y in (10.0, 13.0, 16.0, 19.0, 20.0)]
        assert not inside(part, *run).any()
    assert not inside(part, [NECK / 2 - 0.1, 16.0, MID])[0]
    assert inside(part, [NECK / 2 + 0.1, 16.0, MID])[0]

def test_the_slot_exits_inside_the_band_gap_and_clears_the_horns(part):
    """Slot spans x +-3.5; the gap spans x +-10.1. Nothing between them is cut."""
    assert not inside(part, [0.0, 20.5, MID])[0], "slot does not exit the end"
    assert inside(part, [12.5, 22.0, MID])[0], "the slot has eaten into a horn"

def test_the_lugs_survive_the_assembly(part):
    assert not inside(part, [12.5, BAR_Y, MID])[0], "bore is blocked"
    assert inside(part, [12.5, BAR_Y, MID + 1.5])[0], "horn material is missing"

def test_a_body_as_thick_as_the_cord_is_rejected():
    err = render_failure("down_indicator.scad", bodyT=8.0)
    assert "bodyT must be less than cordDia" in err

def test_a_band_too_wide_for_the_end_is_rejected():
    err = render_failure("down_indicator.scad", bandWidth=24)
    assert "horn thickness" in err

def test_holes_that_break_out_of_the_end_are_rejected():
    err = render_failure("down_indicator.scad", holeY=17)
    assert "cord holes break out" in err

def test_a_thinner_body_still_builds_and_widens_the_neck():
    thin = render("down_indicator.scad", bodyT=6.4)
    wider = 2 * math.sqrt(3.5**2 - (6.4 / 2) ** 2)
    assert wider > NECK
    assert thin.is_watertight
    assert not inside(thin, [wider / 2 - 0.1, 16.0, 6.4 / 2])[0]
```

- [ ] **Step 3: Run the test to verify it fails**

```bash
cd down-indicator && .venv/bin/pytest tests/test_assembly.py -q
```

Expected: FAIL — `down_indicator.scad` does not exist.

- [ ] **Step 4: Write the assembly**

`down-indicator/down_indicator.scad`:

```openscad
// Finger-loop down indicator.
//
// A wrist-worn body carrying a bungee cord that loops over the back of the
// hand and around a finger; which finger the loop sits on is the down.
// See ../2026-08-24-finger-loop-indicator-design.md.
//
// Coordinates: +X across the wrist, +Y along the forearm toward the hand,
// +Z out of the watch face. The body sits on z = 0 (wrist side).

use <lib/body.scad>
use <lib/cord_slots.scad>
use <lib/lugs.scad>

/* [Body] */
bodyLen = 40.0;   // along the forearm
bodyWid = 30.0;   // across the wrist
bodyT   =  6.7;   // derived from cordDia -- see the neck assertion below

/* [Cord] */
cordDia =  7.0;   // hole diameter, and trough diameter
holeY   = 10.0;   // hole centres at (0, +holeY) and (0, -holeY)

/* [Lugs] */
bandWidth    = 20.0;
bandClear    =  0.2;   // added to bandWidth for the lug gap
barStandoff  =  4.5;
tipMargin    =  2.0;
barHoleDia   =  1.1;
tipChamfer   =  0.5;
teardropDown = true;   // apex toward the wrist side, for a face-down print

/* [Quality] */
$fn = 96;

/* [Hidden] */
lugGap   = bandWidth + bandClear;
hornThk  = (bodyWid - lugGap) / 2;
hornProt = barStandoff + tipMargin;
lugToLug = bodyLen + 2 * hornProt;
cordNeck = 2 * sqrt(pow(cordDia / 2, 2) - pow(bodyT / 2, 2));

assert(bodyT < cordDia,
       "bodyT must be less than cordDia or the face troughs never meet");
assert(cordNeck >= 1.2 && cordNeck <= 3.5,
       str("cord neck ", cordNeck, "mm is outside the 1.2-3.5mm usable range"));
assert(hornThk >= 4.0,
       str("horn thickness ", hornThk, "mm is too thin; reduce bandWidth"));
assert(holeY + cordDia / 2 < bodyLen / 2,
       "cord holes break out of the body end");

echo(cordNeck = cordNeck, hornThk = hornThk, lugToLug = lugToLug);

down_indicator();

module down_indicator() {
    difference() {
        union() {
            body_blank(bodyLen, bodyWid, bodyT);
            lug_horns(bodyLen, bodyWid, bodyT, lugGap, hornProt, tipChamfer);
        }
        cord_cutter(bodyLen, bodyT, cordDia, holeY);
        bar_bores(bodyLen, bodyWid, bodyT, lugGap,
                  barStandoff, barHoleDia, teardropDown);
    }
}
```

- [ ] **Step 5: Run the test to verify it passes**

```bash
cd down-indicator && make test
```

Expected: PASS, 37 tests. The echo line reads `cordNeck = 2.02731, hornThk = 4.9, lugToLug = 53`.

- [ ] **Step 6: Export the STL and confirm the build target works**

```bash
cd down-indicator && make stl && ls -l build/down_indicator.stl
```

Expected: `build/down_indicator.stl` exists, roughly 380KB.

- [ ] **Step 7: Write the project README**

`down-indicator/README.md`:

```markdown
# Finger-Loop Down Indicator — OpenSCAD model

A wrist-worn body that anchors a bungee cord looping over the back of the hand
and around a finger. Which finger the loop sits on is the down.

Design and reasoning: [../2026-08-24-finger-loop-indicator-design.md](../2026-08-24-finger-loop-indicator-design.md).

## Build

    make stl      # -> build/down_indicator.stl
    make test     # render the model and assert against the mesh
    make clean

`make` creates `.venv` on first use and installs the pinned dependencies from
`requirements.txt`.

## Parameters

Every parameter is declared at the top of `down_indicator.scad` and can be
overridden without editing the file:

    openscad -o build/wide.stl -D bandWidth=18 down_indicator.scad

| Parameter | Default | Notes |
| --- | --- | --- |
| `bodyLen` | 40.0 | Along the forearm |
| `bodyWid` | 30.0 | Across the wrist |
| `bodyT` | 6.7 | Must be less than `cordDia`, or the slots never open |
| `cordDia` | 7.0 | Hole and trough diameter |
| `holeY` | 10.0 | Hole centres |
| `bandWidth` | 20.0 | 18 if the 4.9mm horns prove marginal |
| `barStandoff` | 4.5 | |
| `tipMargin` | 2.0 | |
| `barHoleDia` | 1.1 | |
| `tipChamfer` | 0.5 | |
| `teardropDown` | true | Apex toward the wrist side, for a face-down print |

Four combinations are rejected outright rather than silently producing an
unbuildable part: a body at or thicker than the cord diameter, a cord neck
outside 1.2–3.5mm, horns thinner than 4.0mm, and holes that break out of the
end.

## Print

Face down — the `z = bodyT` face on the bed. That puts strap tension along the
layers and makes the teardrop bores self-supporting.
```

- [ ] **Step 8: Add it to the repository README**

In the root `README.md`, add a row to the Contents table:

```markdown
| [2026-08-24-finger-loop-indicator-design.md](2026-08-24-finger-loop-indicator-design.md) | Design for the finger-loop down indicator: a wrist body anchoring a bungee cord that loops over a finger. Modelled in OpenSCAD under `down-indicator/`, not in Onshape. |
| [down-indicator/](down-indicator/) | The OpenSCAD model for the above, with a `pytest` suite that renders it and asserts against the mesh. |
```

And add a section after "The mechanical slider down counter":

```markdown
## The finger-loop down indicator

A third device, and the first one whose model is version-controlled here
rather than living in Onshape. A 40 x 30 x 6.7mm body on a 20mm watch strap,
with two 7mm holes opening through side-loading slots to each end; a bungee
cord presses into the slots, runs over the back of the hand and loops over a
finger. The finger is the down selector.

It reuses the down counter's spring-bar lug geometry — 20mm band, 20.2mm gap,
teardrop bores — and nothing else. Its footprint is its own.

See [the design](2026-08-24-finger-loop-indicator-design.md) and
[down-indicator/README.md](down-indicator/README.md).
```

- [ ] **Step 9: Run the whole suite once more**

```bash
cd down-indicator && make test
```

Expected: PASS, 37 tests.

- [ ] **Step 10: Commit**

```bash
git add down-indicator/ README.md
git commit -m "feat(down-indicator): assemble the part, guard its parameters, document it"
```

---

## After the plan

The spec lists three things software cannot settle, all of which need a print:

1. Whether a 2.027mm neck holds a real bungee. Print a slot coupon first.
2. Whether 4.9mm horns survive a wrist. Print a single-end test piece with a real spring bar, as the down counter's lug spec also still owes.
3. Whether the cord binds where it exits under the strap. If it does, the fix is moving the holes off the Y centreline so the slots exit a side edge instead — a parameter change plus a slot direction, not a redesign.

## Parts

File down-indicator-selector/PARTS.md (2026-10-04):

# Slider down counter — parts list

**Draft, started 2026-10-03. Not complete.** A builder cannot yet finish a
working counter from this list. Every figure below comes from the model in
this directory or from the owner, and says which. Where neither says, the
entry reads **unknown**. Nothing here is guessed.

## Printed parts

Build them with `make stl`. Sizes are the models' own.

| Part | Qty | Size | File |
| --- | --- | --- | --- |
| Top shell | 1 | 34 × 79 × 7.1mm | `down_indicator_selector.scad` |
| Bottom shell | 1 | 30 × 75 × 5.1mm | `down_indicator_selector_bottom.scad` |
| Button | 1 | 12 × 12 × 5mm | `down_indicator_selector_button.scad` |

## Bought parts

| Part | Qty | What is known | Source |
| --- | --- | --- | --- |
| Magnets | **unknown** | Common 6mm × 2mm | Owner, 2026-10-03 |
| Pin | **unknown** | The detent is a magnetic pin that slides between the four positions and holds at each. Its size and material are **unknown**. Whether the pin is a separate part or is itself a magnet is **unknown**. | Owner, 2026-10-03 |
| Strap | 0 | None. This is a pocket counter: it is carried in a pocket and has no strap fitting. | Owner, 2026-10-04 |
| Fasteners | 0 | None. The two shells press together. | Owner, 2026-10-03 |
| Glue | **unknown** | Not mentioned anywhere. | — |

Facts from the model that bear on the magnets, stated without drawing a
conclusion from them:

- The button's bore is 6.03mm in diameter and runs the full 5.0mm height of
  the button.
- The bottom shell has four blind holes, 6.03mm in diameter and 3.1mm deep,
  15mm apart.

## Print settings

| Setting | Top shell | Bottom shell | Button |
| --- | --- | --- | --- |
| Material | **unknown** | **unknown** | **unknown** |
| Which face goes on the bed | **unknown** | **unknown** | **unknown** |
| Layer height | **unknown** | **unknown** | **unknown** |
| Nozzle | **unknown** | **unknown** | **unknown** |
| Walls and infill | **unknown** | **unknown** | **unknown** |
| Supports | **unknown** | **unknown** | **unknown** |

## What is still needed to finish this list

1. How many magnets, and where each one sits.
2. The pin: what it is, and its size.
3. Print settings for each part.

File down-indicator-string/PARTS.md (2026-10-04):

# Finger-loop down indicator — parts list

**Draft, started 2026-10-03. Not complete.** Every figure below comes from the
model in this directory or from the owner, and says which. Where neither says,
the entry reads **unknown**. Nothing here is guessed.

## Printed parts

Build it with `make stl`.

| Part | Qty | Size | File |
| --- | --- | --- | --- |
| Body | 1 | 40 × 30 × 6.7mm; 53mm over the lugs | `down_indicator_string.scad` |

## Bought parts

| Part | Qty | What is known | Source |
| --- | --- | --- | --- |
| Cord | 1 | 1/8" (3.2mm) bungee cord. Length **unknown**. How the ends are finished or joined into a loop is **unknown**. | Owner, 2026-10-03 |
| Strap | 1 | A 20mm band, from the lugs as modelled. "Any suitable strap that fits would do". Type and length **unknown**. See the note below. | Model; owner, 2026-10-03 |
| Spring bars | **unknown** | The model has two pairs of lugs with 1.1mm bores, sized for a standard bar with a 1.78mm body and about 0.9mm tips, across a 20.2mm gap. Whether the strap is fitted with spring bars is **unknown**. Bar length is **unknown**. | Model, and the lugs spec |
| Fasteners | 0 | None mentioned. | — |

**Strap width.** The lugs as modelled take a 20mm band (a 20.2mm gap). The
24mm-wide Velcro strap the owner described on 2026-10-03, and the tight fit
that keeps it from sliding, belong to a different counter: the 2 by 2 wrist
counter in [`down-indicator-watch/`](../down-indicator-watch/), as the owner
said on 2026-10-04. [README.md](README.md) still records that strap against
this model and needs the same correction.

Facts from the model that bear on the cord:

- Two through-holes, 7.0mm in diameter, 12mm apart centre to centre.
- From each hole, a groove 2.5mm wide runs to one side edge on the watch face
  and to the other side edge on the wrist side. Each groove's axis is sunk
  1mm into its face.

## Print settings

| Setting | Body |
| --- | --- |
| Which face goes on the bed | Face down: the `z = bodyT` face, which is the watch face. From [README.md](README.md#print). |
| Material | **unknown** |
| Layer height | **unknown** |
| Nozzle | **unknown** |
| Walls and infill | **unknown** |
| Supports | **unknown**. The README says the teardrop bores are self-supporting in this orientation. Nothing is said about the grooves on the bed side. |

## What is still needed to finish this list

1. Cord length, and how the loop is closed.
2. Which strap is used, and whether it is fitted with spring bars.
3. Print settings.

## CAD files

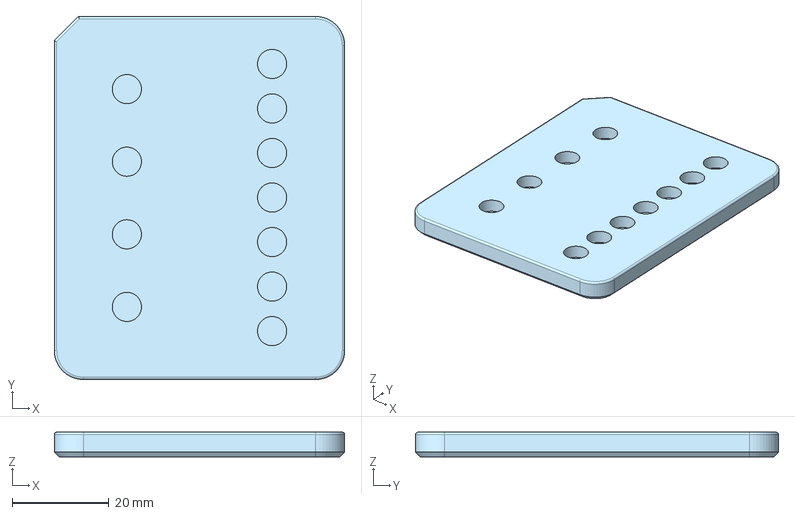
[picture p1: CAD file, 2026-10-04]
down-counter-umpire/Bottom.step
60.0 x 75.0 x 5.10 mm

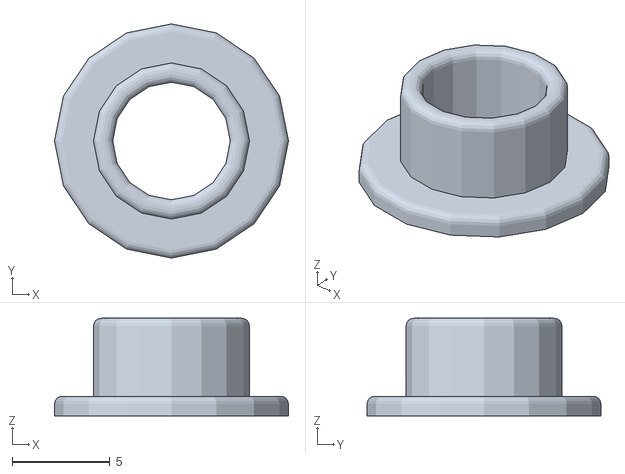
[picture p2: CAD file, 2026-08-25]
down-indicator-selector/reference/onshape-button.stl
12.0 x 12.0 x 5.00

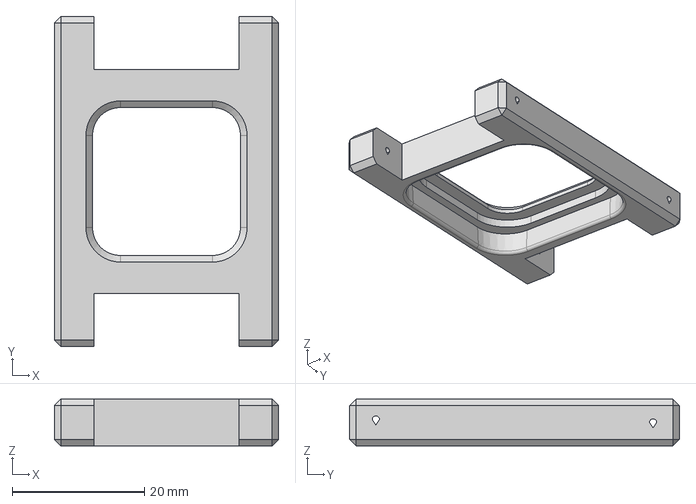
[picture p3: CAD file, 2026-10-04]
down-indicator-watch/top.step
34.0 x 50.0 x 7.10 mm

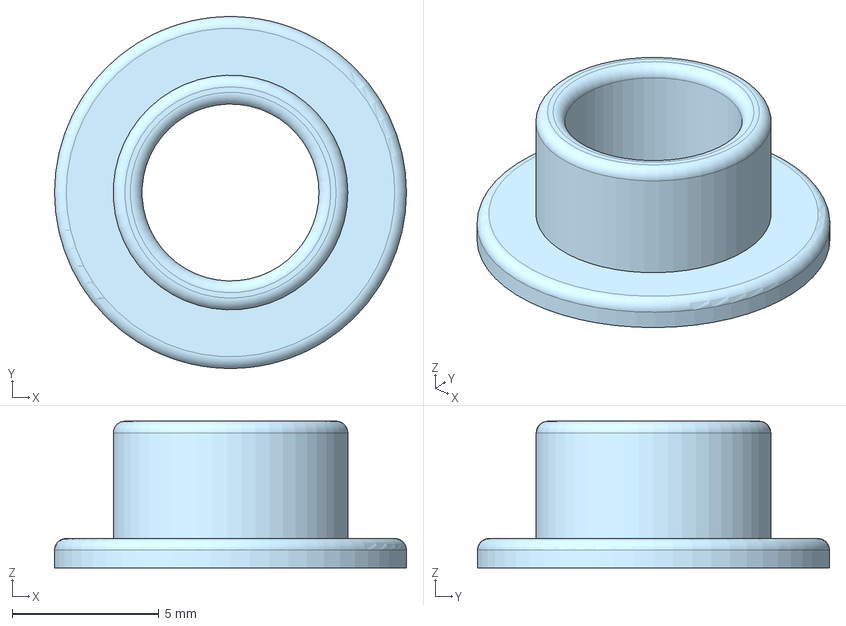
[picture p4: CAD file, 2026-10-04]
down-counter-umpire/button.step
12.0 x 12.0 x 5.00 mm

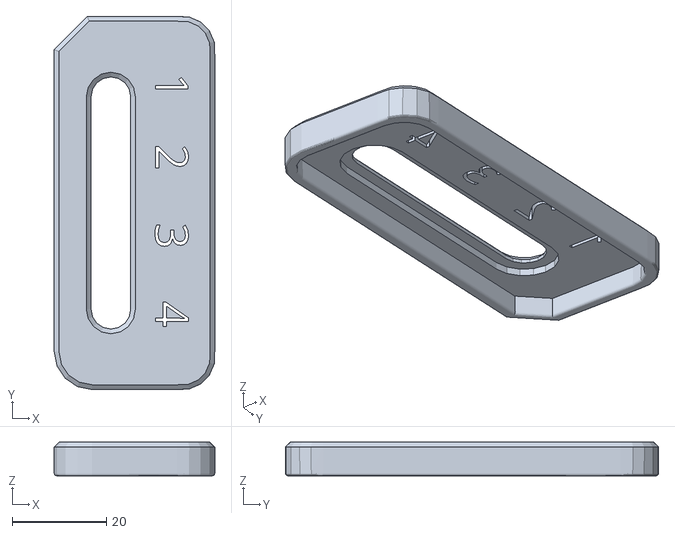
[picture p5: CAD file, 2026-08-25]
down-indicator-selector/reference/onshape-top.stl
34.0 x 79.0 x 7.10

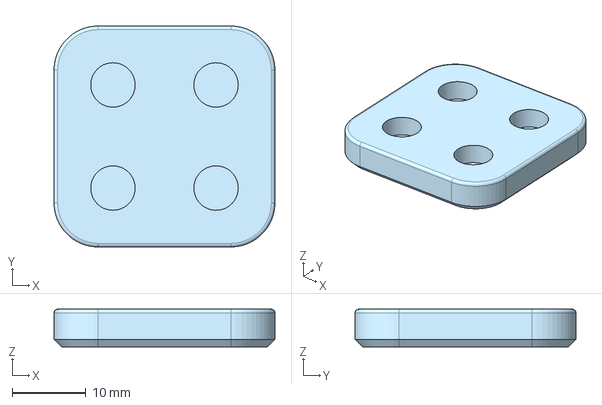
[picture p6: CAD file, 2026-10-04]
down-indicator-watch/Bottom.step
30.0 x 30.0 x 5.10 mm

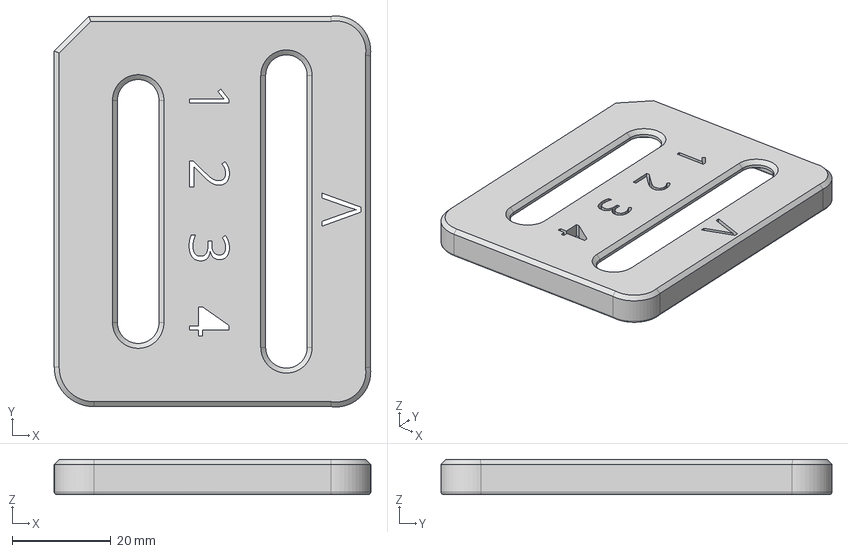
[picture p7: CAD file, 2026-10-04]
down-counter-umpire/top.step
64.1 x 79.1 x 7.10 mm

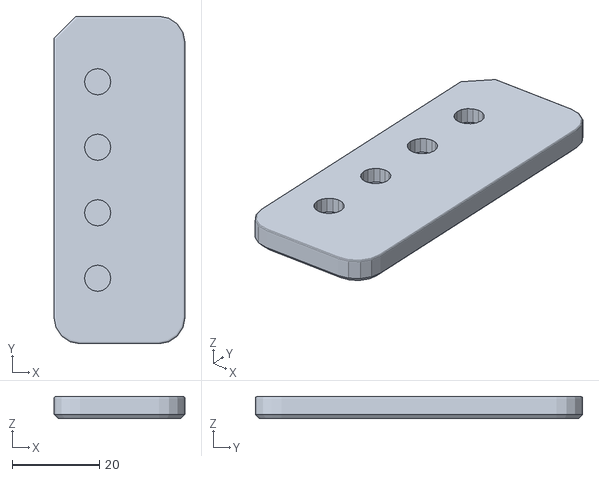
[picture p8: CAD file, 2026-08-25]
down-indicator-selector/reference/onshape-bottom.stl
30.0 x 75.0 x 5.10

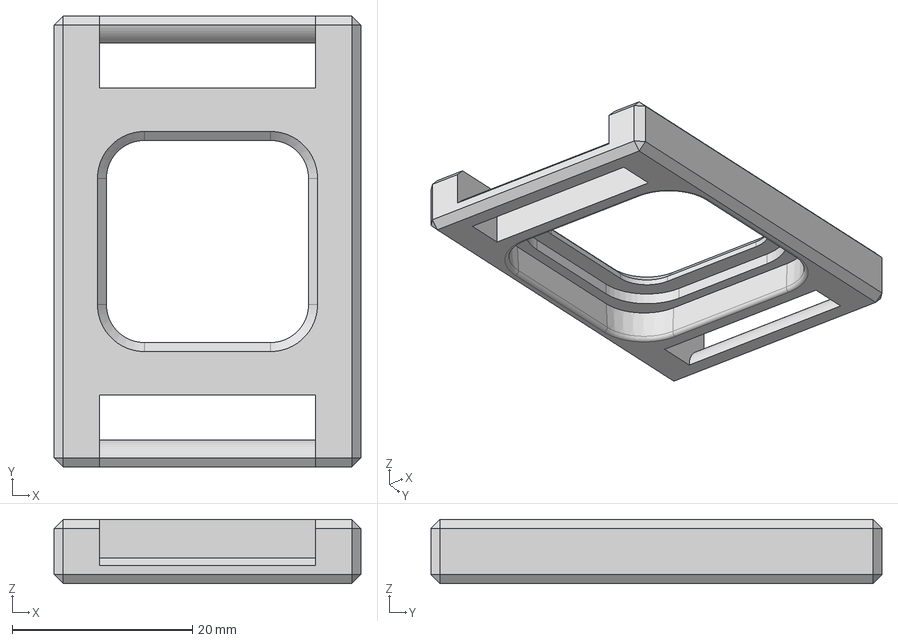
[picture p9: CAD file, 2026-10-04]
down-indicator-watch/top-elastic-strap.step
34.0 x 50.0 x 7.10 mm

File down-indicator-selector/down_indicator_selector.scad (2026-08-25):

// Mechanical down selector -- the top shell.
//
// The top half of the three-part printed slider down counter: the plate a
// referee reads, carrying the slot the button rides in and the numerals 1-4
// that say which down it is. The bottom shell nests into the cavity
// underneath and sets the four stations; the button is captive in the slot
// between them.
//
// Converted from the Onshape Part Studio `top` of document
// 3db840dfeff4095d8508aa97 (the original, do-not-modify copy), measured
// 2026-08-25. See README.md for what the conversion does and does not carry
// over.
//
// Coordinates are Onshape's, kept verbatim rather than recentred, because the
// three parts share a frame: the slot runs from y = 0 to y = 45 on x = 0, and
// those four stations are exactly where the bottom shell's index holes sit.
// +Z is out of the watch face, and z = 0 is the underside of the plate, so
// the plate is z = 0 to +3.1 and the skirt hangs to z = -4.

use <lib/profile.scad>
use <lib/shell.scad>
use <lib/slot.scad>
use <lib/numbers.scad>

/* [Case] */
shellWidth   =  2.0;   // skirt wall, and how far the cavity is inset
plateT       =  3.1;   // solid plate, z = 0 to +plateT
skirtDepth   =  4.0;   // skirt wall, z = -skirtDepth to 0
cornerRadius =  6.0;   // of the cavity; the outer corners add shellWidth
keyCut       =  5.0;   // 45-degree orientation key at the -X/+Y cavity corner
topChamfer   =  1.0;   // 45-degree break around the top face
bottomFillet =  0.5;   // round along both edges of the bottom face
draftAngle   =  3.0;   // on the cavity walls, widest at the ceiling

/* [Slot] */
stationPitch   = 15.0;  // between downs
stationCount   =  4;
holeDiameter   =  8.4;  // the opening at the top face
buttonDiameter = 13.0;  // the pocket under it, which holds the flange captive
pocketDepth    =  1.4;  // how far the pocket reaches up from the underside

/* [Numbers] */
textSize     =  6.85;         // ~6.94mm numerals, as the original measures
textBaseline =  9.4142136;    // the x the numerals stand on
textFont     = "DejaVu Sans"; // the original is Open Sans; see lib/numbers.scad
// Measured ink centres of the original, which are not on the station pitch.
textCentres  = [47.857, 32.219, 15.590, -1.095];
// The counter of the 4 has to be tied back to the plate or it drops out of
// the print -- see lib/numbers.scad, and the Fidelity section of README.md
// for why the original does not do this. The bar crosses the diagonal stroke
// at mid height, anchored in plate on its far side. Tuned for textFont at
// textSize; set tiedNumeral to 0 to cut the numerals as the original does.
tiedNumeral  =  4;
tieBar       = [-3.5, -0.2, 3.85, 4.55];   // across0, across1, up0, up1

/* [Fidelity] */
// How far in from the corner the two +X corner arcs are centred. At the
// corner radius, 8, they would be ordinary tangent fillets; the original has
// them at 7, on arcs of 5*sqrt(2) that are tangent to neither wall. That is
// almost certainly a slip, but it is a half-millimetre slip where it is
// widest, so the default reproduces it. See lib/profile.scad, and the
// Fidelity section of README.md for what it costs.
cornerSwing  =  7.0;

/* [Quality] */
$fn = 96;

/* [Hidden] */
stations = [for (i = [0 : stationCount - 1]) i * stationPitch];
cavX = [-10.0, 20.0];                              // slot centre to each wall
cavY = [-stationPitch, stationPitch * stationCount];
outX = [cavX[0] - shellWidth, cavX[1] + shellWidth];
outY = [cavY[0] - shellWidth, cavY[1] + shellWidth];
outR = cornerRadius + shellWidth;
draftInset = skirtDepth * tan(draftAngle);

assert(bottomFillet <= shellWidth / 2,
       str("bottom fillet ", bottomFillet,
           "mm cannot exceed half the ", shellWidth,
           "mm wall, or the two rounds along the bottom face meet"));
assert(topChamfer < plateT - pocketDepth,
       str("top chamfer ", topChamfer, "mm reaches past the pocket ledge at ",
           pocketDepth, "mm and would break into the slot"));
assert(pocketDepth < plateT,
       "the pocket must stop short of the top face or the slot has no ledge");
assert(buttonDiameter > holeDiameter,
       "the pocket must be wider than the opening or nothing is held captive");
assert(draftInset < shellWidth,
       str("draft takes ", draftInset, "mm off a ", shellWidth,
           "mm wall at the bottom face"));
assert(keyCut + shellWidth < min(cavX[1] - cavX[0], cavY[1] - cavY[0]),
       "the orientation key is bigger than the case");
assert(buttonDiameter / 2 < min(-cavX[0], cavX[1]),
       "the slot pocket breaks out through a cavity wall");

echo(footprint = [outX[1] - outX[0], outY[1] - outY[0], plateT + skirtDepth],
     cavity = [cavX[1] - cavX[0], cavY[1] - cavY[0]],
     draftInset = draftInset,
     ledgeWidth = (buttonDiameter - holeDiameter) / 2);

down_indicator_selector();

module down_indicator_selector() {
    difference() {
        shell_blank(outline(outX, outY, outR, keyCut + shellWidth, cornerSwing, $fn),
                    -skirtDepth, plateT, bottomFillet, topChamfer, $fn);
        cavity_cutter(outline(cavX, cavY, cornerRadius, keyCut, cornerRadius, $fn),
                      -skirtDepth, draftAngle, bottomFillet, $fn);
        slot_cutter(stations, holeDiameter, buttonDiameter, plateT, pocketDepth,
                    topChamfer);
        numbers_cutter(textBaseline, textCentres, textSize, textFont, plateT,
                       tieBar, tiedNumeral);
    }
}

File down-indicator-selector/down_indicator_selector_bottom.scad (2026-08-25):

// Mechanical down selector -- the bottom shell.
//
// The half that nests up inside the top shell and sets where the button
// stops. It is a plain 30 x 75 x 5.1mm plate with four blind holes in its
// upper face, one per down, on the same 15mm pitch as the slot above them.
//
// Converted from the Onshape Part Studio `Bottom` of document
// 3db840dfeff4095d8508aa97 (the original, do-not-modify copy), measured
// 2026-08-25. See README.md.
//
// Coordinates are Onshape's. The plan outline is the same one the top shell's
// cavity is cut to -- literally the same call to `outline` -- so x and y here
// mean what they mean there. z does not: this part is drawn about its own
// z = 0, which is the floor of the four holes. Its top face at z = +3.1 is
// the one that meets the top shell's cavity ceiling, so in the top shell's
// frame this part sits 3.1mm lower than it is drawn here. See README.md,
// which also has the arithmetic on how the two actually fit.

use <lib/profile.scad>
use <lib/shell.scad>

/* [Plate] */
lowerT       =  2.0;   // below the hole floors, z = -lowerT to 0
upperT       =  3.1;   // above them, z = 0 to +upperT -- the holes are this deep
cornerRadius =  6.0;
keyCut       =  5.0;   // 45-degree orientation key at the -X/+Y corner
bottomChamfer =  1.0;  // 45-degree break around the bottom face
topFillet     =  0.5;  // round along the top edge

/* [Holes] */
stationPitch =  15.0;
stationCount =  4;
holeDiameter =  6.03;  // the button's bore is the same size

/* [Quality] */
$fn = 96;

/* [Hidden] */
stations = [for (i = [0 : stationCount - 1]) i * stationPitch];
plateX = [-10.0, 20.0];                            // hole centres to each wall
plateY = [-stationPitch, stationPitch * stationCount];

assert(bottomChamfer + topFillet < lowerT + upperT,
       "the two edge breaks meet in the middle of the plate");
assert(holeDiameter / 2 < min(-plateX[0], plateX[1]),
       "the holes break out through a wall");
assert(holeDiameter / 2 + cornerRadius < stationPitch,
       "the end holes run into the corner radii");

echo(footprint = [plateX[1] - plateX[0], plateY[1] - plateY[0], lowerT + upperT],
     holeDepth = upperT,
     floorUnderHoles = lowerT);

down_indicator_selector_bottom();

module down_indicator_selector_bottom() {
    difference() {
        plate_blank(outline(plateX, plateY, cornerRadius, keyCut, cornerRadius, $fn),
                    -lowerT, upperT, bottomChamfer, topFillet, $fn);
        // Blind from above: floor at z = 0, open at the top face. Extended
        // past that face so the cut breaks out of it cleanly.
        for (y = stations)
            translate([0, y, 0])
                cylinder(h = upperT + 1, d = holeDiameter);
    }
}

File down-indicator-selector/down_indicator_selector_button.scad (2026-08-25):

// Mechanical down selector -- the button.
//
// The thumb piece. A flanged top-hat with a bore through it: the flange sits
// captive in the pocket under the top shell's plate, too wide to pass back
// out through the slot opening, while the boss stands proud through that
// opening for a thumb to push.
//
// Converted from the Onshape Part Studio `button` of document
// 3db840dfeff4095d8508aa97 (the original, do-not-modify copy), measured
// 2026-08-25. See README.md.
//
// It is a solid of revolution, so it is drawn as one: the profile below is
// the half-section in the (radius, z) plane, spun about the axis. Onshape's
// z is kept -- the flange runs z = -1 to 0 and the boss z = 0 to +4.
//
// What passes through the bore is not modelled, here or in Onshape. The bore
// and the bottom shell's holes are both 6.03mm, so something -- a pin, a
// screw -- is meant to run through the button into the hole below it and be
// the detent. The assembly in Onshape is empty and no fastener is drawn, so
// that part of the design is not recorded anywhere. Confirm against a
// physical unit before changing anything here.

use <lib/profile.scad>

/* [Button] */
boreDiameter   =  6.03;  // matches the bottom shell's holes
flangeDiameter = 12.0;   // captive in the 13mm pocket
flangeT        =  1.0;
bossDiameter   =  8.0;   // passes through the 8.4mm slot opening
bossH          =  4.0;
edgeFillet     =  0.4;   // top rim inside and out, and the flange's top edge

/* [Quality] */
$fn = 96;

/* [Hidden] */
rBore   = boreDiameter / 2;
rFlange = flangeDiameter / 2;
rBoss   = bossDiameter / 2;
f       = edgeFillet;

assert(rBore < rBoss, "the bore is wider than the boss it runs through");
assert(rBoss < rFlange, "the flange has to overhang the boss to stay captive");
assert(f < min(rBoss - rBore, rFlange - rBoss, flangeT, bossH),
       str("a ", edgeFillet, "mm fillet does not fit on this section"));

echo(height = flangeT + bossH,
     flangeOverhang = rFlange - rBoss,
     bossWall = rBoss - rBore);

down_indicator_selector_button();

module down_indicator_selector_button() {
    rotate_extrude() polygon(section());
}

// The half-section, walked anticlockwise from the bore at the bottom face.
// Three rounds: the flange's top edge, and both rims at the top of the boss.
function section() = concat(
    [[rBore, -flangeT], [rFlange, -flangeT], [rFlange, -f]],
    arc([rFlange - f, -f], [rFlange, -f], [rFlange - f, 0], $fn),
    [[rBoss, 0], [rBoss, bossH - f]],
    arc([rBoss - f, bossH - f], [rBoss, bossH - f], [rBoss - f, bossH], $fn),
    [[rBore + f, bossH]],
    arc([rBore + f, bossH - f], [rBore + f, bossH], [rBore, bossH - f], $fn)
);

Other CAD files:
down-indicator-string/down_indicator_string.scad
down-indicator-selector/tests/scad/blank_only.scad
down-indicator-string/tests/scad/body_only.scad
down-indicator-string/tests/scad/cord_only.scad
down-indicator-string/tests/scad/logo_only.scad
down-indicator-string/tests/scad/lugs_only.scad
down-indicator/down_indicator.scad

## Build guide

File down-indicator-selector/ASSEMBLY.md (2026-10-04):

# Slider down counter — assembly steps

**Draft, started 2026-10-03. Not complete.** These steps have not been
followed by anyone but the owner, and the step for the magnets is missing. Where a step is not known it reads **unknown**. Nothing here is
guessed. Parts are in [PARTS.md](PARTS.md).

## What the model tells us

These come from the geometry and are checked by `tests/test_fit.py`. See
[README.md](README.md#how-the-three-fit).

- The button's 12mm flange sits in the 13mm pocket under the top shell's
  plate. Its 8mm boss passes up through the 8.4mm slot opening. The flange
  cannot pass through that opening, so **the button goes in from underneath,
  before the bottom shell**.
- The bottom shell goes into the cavity under the top shell, with its four
  holes facing the button. The two shells have a 45° key at one corner, so
  they go together only one way round.
- The shells are a press fit, about 0.18mm of interference per side. The owner
  confirmed on 2026-10-03 that they are meant to press together.
- Once pressed home, the bottom shell stands 1.1mm proud of the top shell's
  skirt. The case is 8.2mm thick, and 10.1mm over the button.

## Steps

| # | Step | Status |
| --- | --- | --- |
| 1 | Print the three parts. | Print settings **unknown**. See PARTS.md. |
| 2 | Fit the magnets and the pin. | **Unknown.** How many magnets, where they sit, which way round they face, and whether they are pressed or glued in are not recorded. |
| 3 | Place the button in the pocket on the underside of the top shell, boss through the slot. | From the model. |
| 4 | Line up the keyed corners and press the bottom shell into the top shell until it seats. | From the model, and the owner's word that it is a press fit. How much force it takes, and whether a tool is needed, is **unknown**. |
| 5 | Check: the button slides the length of the slot and holds at each of the four numbers. | The check follows from how the counter works. How firmly it should hold is **unknown**. |

There is no strap to fit. The owner said on 2026-10-04 that this counter is
carried in a pocket.

## Taking it apart

**Unknown.** The repository does not record whether the press fit can be
opened again without damage. This matters for replacing parts.

## What is still needed to finish this page

1. Step 2, from the owner: the magnets and the pin.
2. One person other than the owner following these steps from a fresh print.

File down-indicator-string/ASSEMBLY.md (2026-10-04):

# Finger-loop down indicator — assembly steps

**Draft, started 2026-10-03. Not complete.** Where a step is not known it reads
**unknown**. Nothing here is guessed. Parts are in [PARTS.md](PARTS.md).

## What the model tells us

- The cord passes through two 7.0mm holes in the body.
- At each hole, a 2.5mm groove leads away to one side on the watch face and
  to the opposite side on the wrist side.
- The cord named by the owner is 3.2mm, which is wider than the 2.5mm groove.
- The strap passes between the lugs at each end of the body. The gap is
  20.2mm.

## Steps

| # | Step | Status |
| --- | --- | --- |
| 1 | Print the body, watch face down. | Orientation from the README. Other print settings **unknown**. |
| 2 | Cut the cord to length. | Length **unknown**. |
| 3 | Fit the cord to the body. | **Unknown.** The model's own notes say the cord is threaded through the holes. A later commit calls the groove a "snap-in groove". Which the owner does, and in what order, is not recorded. |
| 4 | Close the cord into a loop. | **Unknown.** |
| 5 | Fit the strap. | **Unknown.** The lugs take spring bars across a 20.2mm gap, for a 20mm band. Which strap is used is not recorded. |
| 6 | Check: the body does not slide on the wrist, and the loop reaches each finger and stays on it. | The check follows from how the indicator works. No test of it is recorded. |

## Open tests the design calls for

Recorded in the design documents and not yet done, as far as the repository
shows:

- Whether the groove holds a real cord.
- Whether the lugs are strong enough on a wrist.
- Whether the 1mm edge chamfer is comfortable on the wrist side.
- Whether the bed-side groove prints smooth enough not to drag the cord.

## What is still needed to finish this page

1. Steps 2 to 5, from the owner.
2. One person other than the owner following these steps from a fresh print.

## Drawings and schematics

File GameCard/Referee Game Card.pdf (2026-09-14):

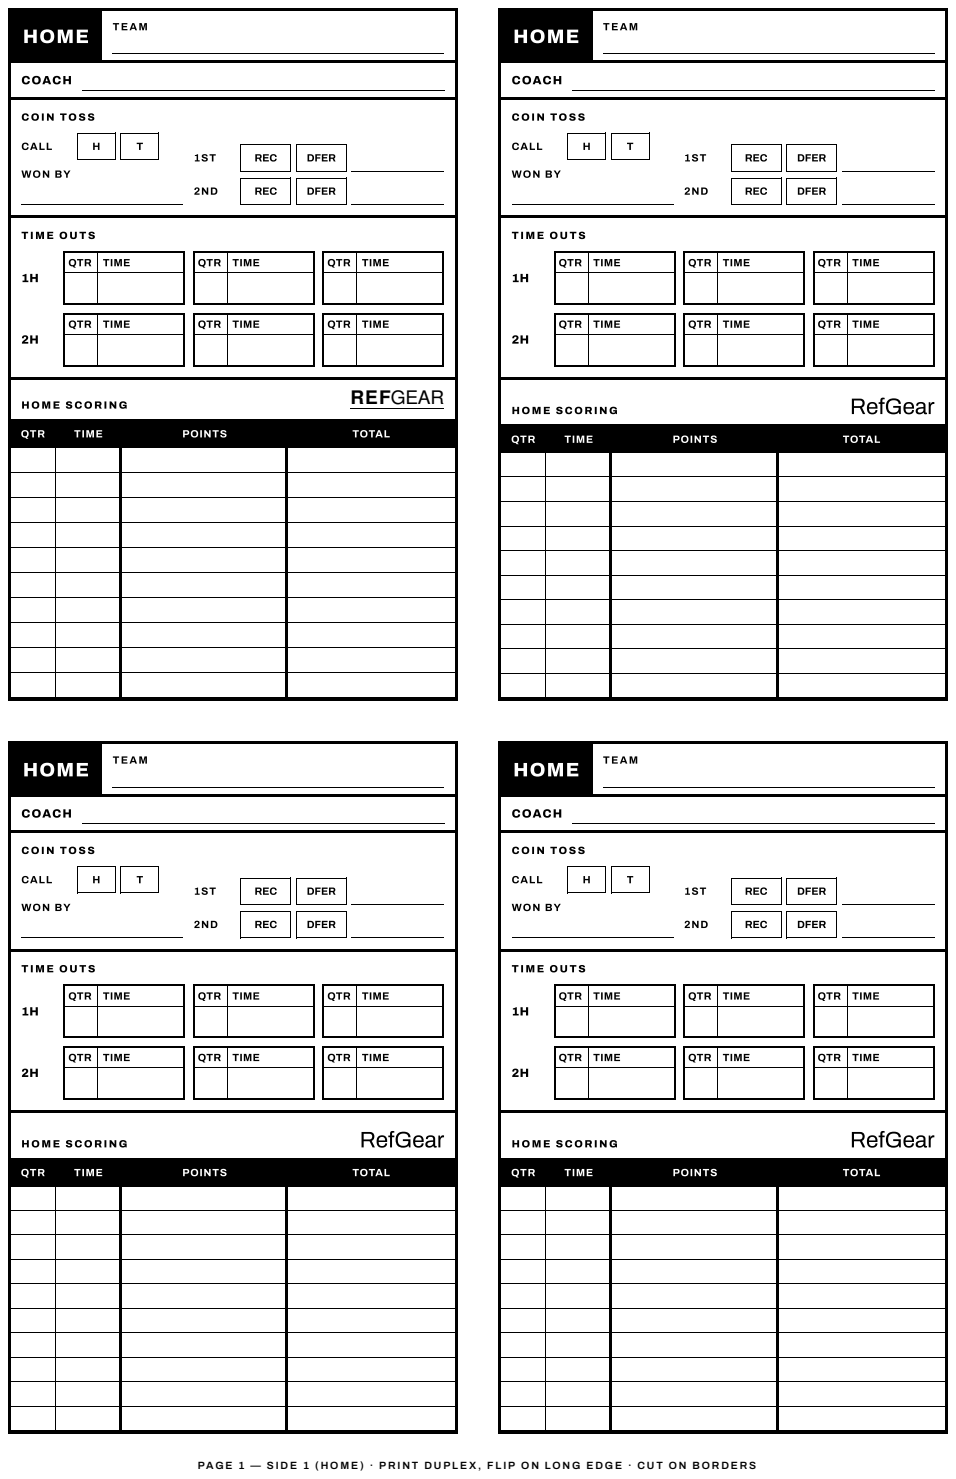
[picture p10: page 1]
REFGEAR

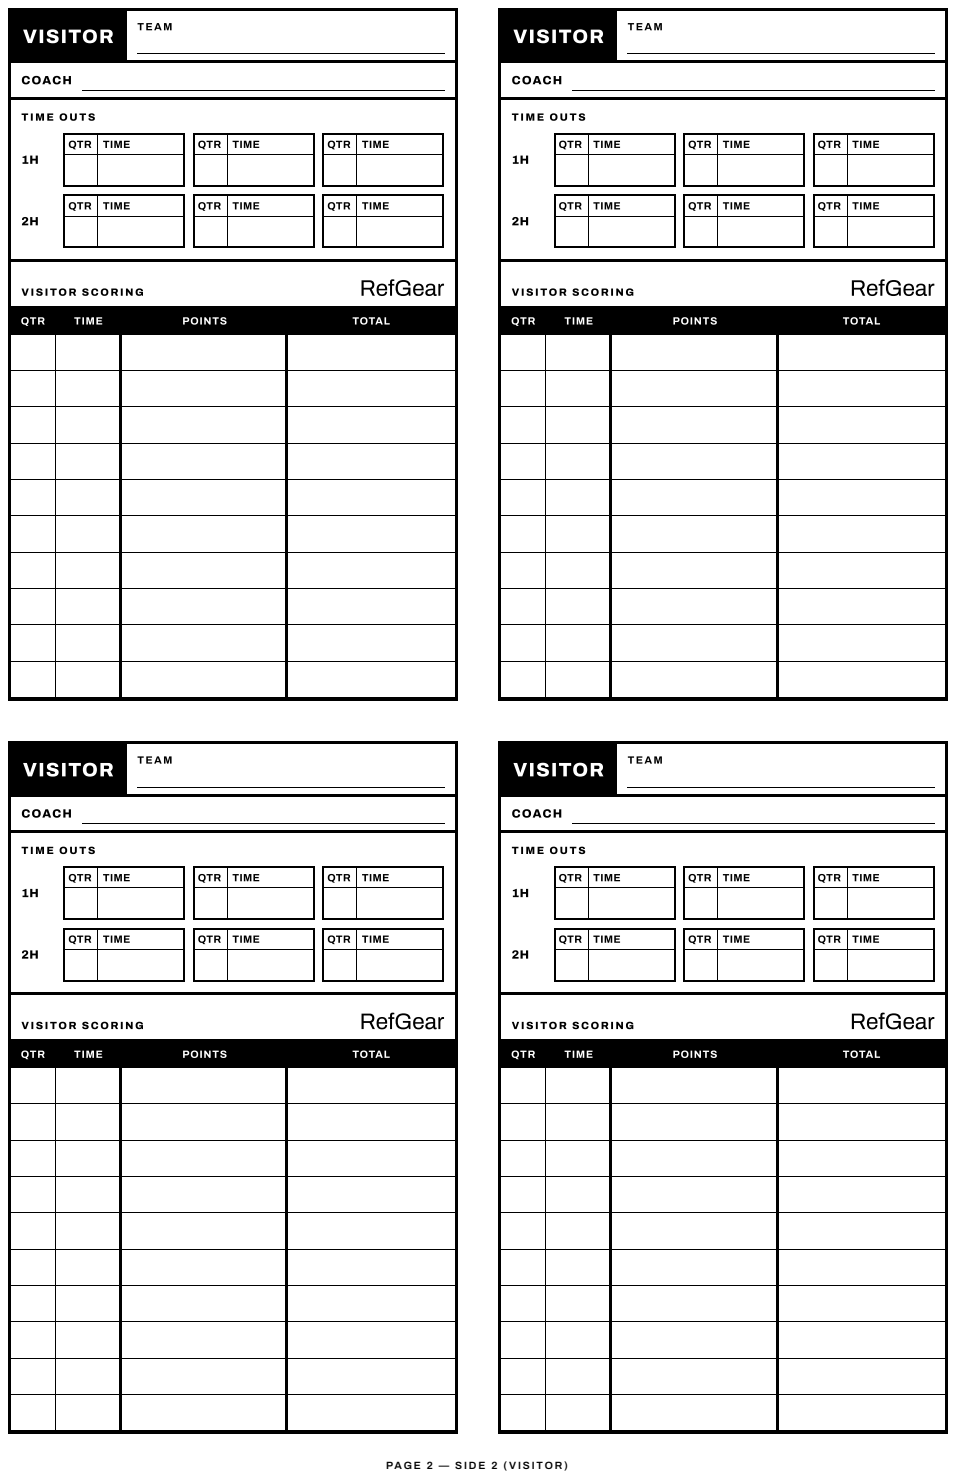
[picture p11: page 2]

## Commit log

2026-08-23 Split the mechanical down counter out of watchy-ref-counter
    The down-counters folder documented a printed slider down counter whose
    models live in Onshape. It shared a repository with the electronic
    Watchy-based ref counter for no reason beyond where the work happened,
    and that proximity had already caused one concrete error: the first
    revision of the lugs spec borrowed case dimensions from the Watchy
    waterproof case spec, and every figure derived from them was wrong.
    Extracted from watchy-ref-counter at e6a5a74. The three documents are
    carried over unchanged apart from the passages that said "this
    repository" and meant the other one; those now name and link it.
    Licensed under the Open Com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
2026-08-24 docs: spec and implementation plan for the finger-loop down indicator
    A wrist-worn body anchoring a bungee cord that loops over a finger; the
    finger is the down selector. Unlike the mechanical slider counter, this
    model is version-controlled here as OpenSCAD source rather than living
    in Onshape.
2026-08-24 feat(down-indicator): scaffold OpenSCAD project and body blank
    [body_only.scad]
2026-08-24 feat(down-indicator): add the two 7mm cord holes
    [cord_only.scad]
2026-08-24 feat(down-indicator): open the cord holes to the ends with face troughs
    Cut a 7mm trough into both the watch face and the wrist side, running
    from each hole out past the body end. Since bodyT (6.7mm) is thinner
    than the trough diameter (7.0mm), the two troughs overlap at
    mid-thickness, leaving an open slot with a ~2.03mm neck that the cord
    presses into from the side rather than being threaded.
    Retires test_holes_remove_exactly_two_cylinders, whose hole-only
    volume figure is no longer observable now that cord_cutter also cuts
    troughs; test_holes_and_troughs_together carries the combined
    closed-form check forward.
2026-08-24 feat(down-indicator): add 20mm spring-bar lug horns
    Four additive horns (lug_horns), flush with the side walls, protruding
    6.5mm past each end face with 0.5mm chamfered tip corners. Horn
    thickness is derived from wid/gap, not a parameter. A 0.5mm root
    overlap into the body avoids coincident-plane CGAL unions.
    [lugs_only.scad]
2026-08-24 feat(down-indicator): add teardrop spring-bar bores
    Subtracts four teardrop-profiled spring-bar bores through the lug horns.
    The teardrop replaces the unsupported crown of a horizontal round hole with
    two 45-degree flanks so the bore prints without sagging when the case is
    oriented face down. apexDown controls which way the apex points, tested in
    both orientations via the -D override path Task 6 depends on.
    [lugs_only.scad]
2026-08-24 feat(down-indicator): assemble the part, guard its parameters, document it
    [down_indicator.scad]
2026-08-24 fix(down-indicator): guard the merged-hole and horn-deleting cases
    Two parameter combinations rendered without a nonzero exit code while
    producing an unusable part:
    - 2*holeY <= cordDia merges the two cord holes; the troughs join into
    a channel at mid-thickness and sever the slab into two bodies (or,
    exactly at the boundary, a non-manifold STL). Guarded with a 2.0mm
    minimum inter-hole wall, matching the down counter's wall thickness;
    the default leaves 13.0mm.
    - tipChamfer >= hornThk/2 crosses two vertices of horn_profile's
    polygon. OpenSCAD reported an unclosed mesh four times, exited 0, and
    wrote a bare slab with no lugs at all. Guarded in down_indicator.scad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
    [down_indicator.scad]
2026-08-24 fix(down-indicator): make 'make stl' report the built file
    The stl target is phony with a single prerequisite and no recipe, so once
    build/down_indicator.stl was current make printed 'Nothing to be done for
    stl' -- which reads as a failure when it actually means the STL is ready.
    Give the target a recipe that names the file and its size.
2026-08-25 feat(down-indicator): route each hole's troughs to opposite side edges
    Each hole's face trough now runs out to +X and its wrist trough to -X, so a
    strand drops through the hole and turns into the opposite channel, making two
    right-angle bends inside the body. The bends are the retention -- no knot and
    no pinch fit. The cord is threaded rather than pressed in, which is the
    deliberate consequence: away from the hole the two channels never meet.
    This retires the neck. bodyT = 6.7 was previously derived from the neck width
    and is now a free choice; the binding constraint becomes the floor under each
    trough, bodyT - cordDia/2, asserted at 2.0mm minimum (3.2mm at defaults). The
    two cordNeck guard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
    [cord_only.scad, down_indicator.scad]
2026-08-25 feat(down-indicator): chamfer the outer edges 1mm at 45 degrees
    Every outer wall is now bevelled where it meets each face -- both side walls,
    all four horn tips, and both walls of the band gap. The part is 6.7mm of hard
    plastic against a wrist and the long side walls are what press into it.
    The chamfers are exact half-spaces rather than swept or stepped surfaces:
    every outer wall is straight and every outer solid is a straight extrusion, so
    the material to remove at a wall with outward normal n at distance d is
    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
    [down_indicator.scad]
2026-08-25 fix(down-indicator): leave the horns' inner faces square
    The band gap is sized to the strap -- 20.2mm for a 20mm band. Bevelling the
    faces the strap bears against opened it to 22.2mm at each face while leaving
    20.2mm in the middle, so a strap sized to the gap would sit loose top and
    bottom and rock in its own slot. Those four cutters are removed and the horn
    interiors keep their full 6.7mm height.
    The body end faces at the base of the gap keep their chamfer: nothing bears on
    them, they only need to not be sharp. That is now the only bounded cutter here
    -- the per-horn quadrant clipping goes away with the cutters that needed it.
    Volume 7255.443 -> 7278.693mm3. Gap now measures 20.2mm at eve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
2026-08-25 refactor(down-indicator): rename down_indicator to down_indicator_string
    Renames the model file, its top-level module, and the build output:
    down_indicator.scad -> down_indicator_string.scad
    module down_indicator() -> module down_indicator_string()
    build/down_indicator.stl -> build/down_indicator_string.stl
    All render() and render_failure() call sites in the suite follow, as do the
    Makefile target and the project README.
    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
    [down_indicator_string.scad]
2026-08-25 refactor: rename the down-indicator directory to down-indicator-string
    Completes the rename begun in b45953c. The directory keeps the repository's
    hyphenated convention, so down_indicator_string.scad now lives in
    down-indicator-string/.
    Path references in the root README and the design spec follow. The spec's
    mention of a 'down-indicator wristband' is left alone -- that names the
    commercial product this design is modelled on, not this directory.
    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
    [body_only.scad, cord_only.scad, down_indicator_string.scad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]
2026-08-25 Convert the slider down counter to OpenSCAD
    All three parts of the mechanical counter now build from OpenSCAD alone,
    under down-indicator-selector/. Converted from the feature trees of the
    original Onshape document 3db840dfeff4095d8508aa97 -- its variables, sketch
    coordinates, and the depths, angles and radii on its extrudes, draft,
    chamfers and fillets -- not by tracing meshes.
    top shell 7819.4mm^3 against Onshape's 7832.5
    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
    [blank_only.scad, down_indicator_selector.scad, down_indicator_selector_bottom.scad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]
2026-08-27 feat(down-indicator-string): decouple the cord trough from the hole
    The trough diameter was pinned to cordDia and its axis pinned to the face
    it is cut into, so the only way to change the groove was to change the
    bore. Split them: troughDia sizes the groove on its own, and troughOffset
    slides the axis off the face -- positive sinks it for a deeper-than-
    half-round groove that closes over the cord under a lip, negative lifts it
    for a shallower one, 0 keeps today's clean half-round.
    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
    [down_indicator_string.scad]
2026-08-27 Narrow the cord troughs into a snap-in groove
    Now that the trough is free of the bore, set it up as a channel the cord
    presses into rather than a half-round the width of the hole:
    troughDia 7.0 -> 2.5 a channel sized to the cord, not to the 7mm bore
    troughOffset 0 -> 1 sinks the axis a millimetre under the face, so
    the slot opens 1.5mm into a 2.5mm groove and the
    cord has to snap past the lips to seat
    holeY 10 -> 6 hole centres 12mm apart rather than 20
    Trough depth lands at 2.25mm with 4.45mm of floor left under it, well over
    the 2.0mm minimum.
    [down_indicator_string.scad]
2026-08-27 fix(down-indicator-string): repair the tests broken by the trough split
    416dd68 gave cord_cutter() two more parameters and reworded an assertion,
    but did not carry either through to the tests, and the suite was never run.
    It went from 50 green to 33 passed, 6 failed, 11 errors.
    cord_only.scad still called cord_cutter() with four arguments, so
    troughOffset arrived undefined and every translate() in the trough poisoned
    itself with undef -- which took out all of test_cord_slots.py. The fixture
    now declares troughDia = 7.0 and troughOffset = 0.0 explicitly, the
    geometry those tests were written against, so what they assert is unchanged.
    test_holes_that_break_out_of_the_end_are_rejected matched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
    [cord_only.scad]
2026-08-27 feat: add the RefGear wordmark SVG
    Adds the RefGear logo as a text-based SVG wordmark for use as
    branding on printed parts.
2026-08-27 feat(down-indicator-string): deboss the RefGear wordmark into both faces
    REF in Archivo Black butted against GEAR in Archivo Regular over a
    full-width rule, recessed 0.5mm into the watch face and the wrist face,
    sitting in the clear band past the cord holes at the wrist end. The
    wrist copy is mirrored so it reads the right way round on that face
    rather than showing through reversed.
    refgear-logo.svg is the source of the layout but cannot be the source
    of the geometry: OpenSCAD's SVG reader drops <text> outright, so
    importing that file yields the bare underline and nothing else. The
    mark is rebuilt out of text() instead, against two static Archivo faces
    vendored under fonts/ (SIL OFL). Both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
    [down_indicator_string.scad, logo_only.scad]
2026-08-27 feat(down-indicator-string): turn the wordmark a quarter-turn clockwise
    The mark now reads along the forearm rather than across the wrist, which
    means it runs alongside the cord holes instead of past them and so cannot
    sit centred: at x = 0 it would be cut straight through both bores.
    Which side it moves to is not a free choice. The watch-face troughs run
    out to +X and the wrist-side ones to -X, so the mark belongs on -X --
    and the mirror the wrist copy already needed, to read the right way
    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
    [down_indicator_string.scad, logo_only.scad]
2026-10-03 docs: record the detent, shell fit, strap and cord as the owner confirmed them
    The slider's detent is a magnetic pin, and its two shells are meant to press
    together. The finger-loop indicator uses 1/8" bungee cord and a 24mm Velcro
    strap. The lugs as modelled take a 20mm band; that difference is noted, not
    resolved. No model or test is changed.
2026-10-03 test(down-indicator-string): bring the assembly tests up to the snap-in groove
    a0deae2 moved the cord holes from +-10mm to +-6mm and narrowed the surface
    troughs from 7mm to 2.5mm, sunk 1mm into each face. tests/test_assembly.py
    still described the old cord path, so five tests failed on a clean checkout
    although the part is sound.
    Tests only. No model file is touched.
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2026-10-03 docs(down-indicator-string): bring the parameter table in line with the model
    holeY is 6.0, not 10.0. troughDia and troughOffset were missing. cordDia
    is the through-hole only. The list of rejected combinations described an
    earlier design.
2026-10-03 docs: record the magnet size and the owner's game use of the slider
    As the owner said on 2026-10-03: the magnets are common 6mm x 2mm, and the
    unit used in at least 10 games this season is down-indicator-selector,
    'the one with 4 slots in a 2 by 2 configuration'.
2026-10-03 docs: start a parts list and assembly steps for each model
    Drafts. Every figure is from the model or from the owner and says which.
    Everything else is marked unknown; no size is guessed.
2026-10-04 add other devices and links to their source
    [Bottom.step, button.step, top-elastic-strap.step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]
2026-10-04 docs(down-counter-umpire): describe the Umpire Counter, its parts and how it goes together
    Sizes measured from the STEP files. Fit checked on the solids. Nothing
    printed. Unknowns are listed; no size is guessed. No model file changed.
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2026-10-04 docs: correct the field use: the slider is a pocket counter, the wrist counter is the 2 by 2
    The owner said on 2026-10-04 that the counter worn in at least 10 games is
    the 2 by 2 wrist counter in down-indicator-watch/, and that the slider is
    carried in a pocket and has also been used in games. The strap, the "4 slots
    in a 2 by 2" and the count of 10 games are taken out of the slider's pages.
2026-10-04 docs: take the strap off the slider's pages and the 24mm strap off the finger loop's
    The owner said on 2026-10-04 that the slider is a pocket counter, and that
    the counter worn on a 24mm Velcro strap in at least 10 games is the 2 by 2
    wrist counter in down-indicator-watch/. The slider's parts list and steps no
    longer ask for a strap fitting. The finger loop's pages no longer record the
    24mm strap against it.
2026-10-04 docs(down-indicator-watch): record the shared button, pin and magnets, and the field use
    The owner said on 2026-10-04 that this is the counter worn in at least 10
    games, and that it uses the same button, pin and magnets as the slider and
    the Umpire Counter. The button is no longer marked as inferred.
2026-10-04 docs: add a repair guide site for the four counters, for GitHub Pages
    A static site in docs/: a front page and one repair guide each for the
    pocket slider, the finger loop, the 2 by 2 wrist counter and the Umpire
    Counter. Plain HTML and one stylesheet, no build step. .nojekyll makes
    Pages serve the files as they are.
    Each guide names the parts, the tools, how to open, how to replace each
    part, how to close, and what not to force. Every fact comes from the
    model files or from the owner and is marked with which. Steps nobody has
    done on a printed unit, and facts not recorded, are marked on the page.
    No model file is changed.
    tests/test_docs_site.py checks the pages are well formed, every gui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
